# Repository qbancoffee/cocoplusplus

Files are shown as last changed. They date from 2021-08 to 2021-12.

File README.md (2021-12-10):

# CoCo++
I spent some time transcribing the CoCo 3 schematic into KiCAD to contribute to the bit preserve project.
Using that schematic, I created a drop in replacement board which I subsequently ordered, assembled, and tested.
At this point I consider that project done and time to move on. If you are interested in the bit preserve
project here is the link.<br>
[Bit Preserve, recreating classic computer schematics](https://github.com/baldengineer/bit-preserve)

So now it's time to have fun....<br>
I want to base this board on the CoCo 3 for several reasons.

- It's the latest real CoCo.
- I never used one in my youth.
- When people upgrade to to the GIME-X, they may want to use their otherwise unused GIME
- If used with a GIME-X then there would be a new CoCo added to the world. 

To start this I stripped the CoCo 3 portion out of the bit-preserve project and
created this repository so that I could make changes to the board that I would like to see. I'm making
this available so that anyone can contribute ideas and expertise.

### Goals
I still don't know what all of the goals are but I'll list some ideas that I've had or that others have mentioned or recommended.
- Having fun
- Mod for potential DMA
- USB keyboard
- Reduce overall size 
- A different form factor
- [Fit it in a polycase ZN-45](https://www.polycase.com/zn-45)
- HDMI or VGA out
- Composite out
- Surface mount components
- 12V power supply with standard barrel connector
- Replace DAC/ADC chip with equivalent circuitry
- Replace SALT chip with equivalent circuitry

### Videos
- [Testing new CoCo 3 board](https://youtu.be/XzGmMZHgejc)
- [Running NitrOS 9 Ease Of Use](https://youtu.be/wSlYcxvCpys)

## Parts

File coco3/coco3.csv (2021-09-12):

Reference | Quantity | Value | Footprint | Datasheet | Manufacturer part# | Vendor | Vendor part# | Manufacturer 2nd part# | Vendor 2nd part# | C90157 | LCSC | MMBT9014C | AVAILABILITY | DESCRIPTION | MF | MP | PACKAGE | PRICE
BREAKOUT0 | 1 | Conn_01x18_Male | Connector_PinHeader_2.54mm:PinHeader_1x18_P2.54mm_Vertical | ~
C1004 C1003 C1002 | 3 | .47uF | Capacitor_SMD:C_0805_2012Metric_Pad1.18x1.45mm_HandSolder | https://datasheet.lcsc.com/lcsc/1810251812_Samsung-Electro-Mechanics-CL21B474KBFNNNE_C13967.pdf | CL21B474KBFNNNE | JLCPCB | C13967
C15 C63 | 2 | 220uF 25V | Capacitor_SMD:CP_Elec_8x10 | https://datasheet.lcsc.com/lcsc/1809291333_Lelon-VEJ221M1ETR-0810_C134765.pdf | VEJ221M1ETR-0810 | JLCPCB | C134765
C18 C19 C23 C22 | 4 | 1800pF | Capacitor_SMD:C_0805_2012Metric_Pad1.18x1.45mm_HandSolder | https://datasheet.lcsc.com/lcsc/1811061740_FH-Guangdong-Fenghua-Advanced-Tech-0805B182K500NT_C1722.pdf | 0805B182K500NT | JLCPCB | C1722
C2 C56 C55 | 3 | 10uF 25v | Capacitor_SMD:CP_Elec_4x5.3 | https://datasheet.lcsc.com/lcsc/1809291326_Lelon-VE-100M1ETR-0405_C134721.pdf | VE-100M1ETR-0405 | JLCPCB | C134721
C24 | 1 | 10uF NP | Capacitor_THT:C_Radial_D6.3mm_H5.0mm_P2.50mm | https://products.nichicon.co.jp/en/pdf/XJA043/e-uvp.pdf | UVP1E100MDD1TD | digikey | 493-12688-1-ND
C26 C4 C1 C28 C14 C6 C7 C13 C47 C48 C1001 C51 C50 C42 C39 C41 C38 C40 C12 C8 | 20 | .1uF | Capacitor_SMD:C_0805_2012Metric_Pad1.18x1.45mm_HandSolder | https://datasheet.lcsc.com/lcsc/1811121310_Samsung-Electro-Mechanics-CL21A106KAYNNNE_C15850.pdf | CL21A106KAYNNNE | JLCPCB | C15850
C27 | 1 | 100uF 16v | Capacitor_SMD:CP_Elec_6.3x5.3 | https://datasheet.lcsc.com/lcsc/1811051603_Lelon-VEJ101M1CTR-0605_C164064.pdf | VEJ101M1CTR-0605 | JLCPCB | C164064
C29 | 1 | 4700uF 25V | Capacitor_SMD:CP_Elec_18x22 | https://datasheet.lcsc.com/lcsc/1811051717_Lelon-VEJ472M1ETR-1821_C249676.pdf | VEJ472M1ETR-1821 | JLCPCB | C249676
C3 | 1 | 1uF 50V | Capacitor_SMD:CP_Elec_4x5.4 | https://datasheet.lcsc.com/lcsc/2105211834_Honor-Elec-RVT1H1R0M0405_C3348.pdf | RVT1H1R0M0405 | JLCPCB | C3348
C34 | 1 | 100pF | Capacitor_SMD:C_0805_2012Metric_Pad1.18x1.45mm_HandSolder | https://datasheet.lcsc.com/lcsc/1810241824_Samsung-Electro-Mechanics-CL21C101JBANNNC_C1790.pdf | CL21C101JBANNNC | JLCPCB | C1790
C36 C25 C49 C17 C16 C21 C20 C57 | 8 | .022uF | Capacitor_SMD:C_0805_2012Metric_Pad1.18x1.45mm_HandSolder | https://datasheet.lcsc.com/lcsc/1810191222_Samsung-Electro-Mechanics-CL21B223KBANNNC_C1729.pdf | CL21B223KBANNNC | JLCPCB | C1729
C5 C53 C52 | 3 | .033uF | Capacitor_SMD:C_0805_2012Metric_Pad1.18x1.45mm_HandSolder | https://datasheet.lcsc.com/lcsc/1811061723_FH-Guangdong-Fenghua-Advanced-Tech-0805B333K500NT_C1739.pdf | 0805B333K500NT | JLCPCB | C1739
C54 | 1 | 470uF 16V | Capacitor_SMD:CP_Elec_8x10 | https://datasheet.lcsc.com/lcsc/1809291327_Lelon-VEJ471M1CTR-0810_C176671.pdf | VEJ471M1CTR-0810 | JLCPCB | C176671
C60 | 1 | 33pF | Capacitor_SMD:C_0805_2012Metric_Pad1.18x1.45mm_HandSolder | https://datasheet.lcsc.com/lcsc/1810191222_Samsung-Electro-Mechanics-CL21C330JBANNNC_C1814.pdf | CL21C330JBANNNC | JLCPCB | C1814
C61 C37 C10 C11 | 4 | 39pF | Capacitor_SMD:C_0805_2012Metric_Pad1.18x1.45mm_HandSolder | https://datasheet.lcsc.com/lcsc/1810191333_Walsin-Tech-Corp-0805N390J500CT_C296098.pdf | 0805N390J500CT | JLCPCB | C296098
C64 | 1 | 150pF | Capacitor_SMD:C_0805_2012Metric_Pad1.18x1.45mm_HandSolder | https://datasheet.lcsc.com/lcsc/1811061722_FH-Guangdong-Fenghua-Advanced-Tech-0805B151K500NT_C1716.pdf | 0805B151K500NT | JLCPCB | C1716
C68 C59 C58 | 3 | 1000pF | Capacitor_SMD:C_0805_2012Metric_Pad1.18x1.45mm_HandSolder | https://datasheet.lcsc.com/lcsc/1808311543_Samsung-Electro-Mechanics-CL21B102KBCNNNC_C46653.pdf | CL21B102KBCNNNC | JLCPCB | C46653
C9 | 1 | 100uF 16V | Capacitor_SMD:CP_Elec_6.3x5.3 | https://datasheet.lcsc.com/lcsc/1811051603_Lelon-VEJ101M1CTR-0605_C164064.pdf | VEJ101M1CTR-0605 | JLCPCB | C164064
CN1 | 1 | Conn_02x20_Odd_Even | coco2:EBC20DRAS | https://s3.amazonaws.com/catalogspreads-pdf/PAGE50-51%20.100%20LP%20DS%20EYE%20RA.pdf | EBC20DRAS | digikey | S9672-ND
CN2 | 1 | Conn_01x16_Female | Connector_PinHeader_2.54mm:PinHeader_1x16_P2.54mm_Vertical | https://www.te.com/commerce/DocumentDelivery/DDEController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 | 6-520415-6 | digikey | A144434-ND
CN3 | 1 | Conn_02x05_Odd_Even | Connector_PinHeader_2.54mm:PinHeader_2x05_P2.54mm_Vertical | https://drawings-pdf.s3.amazonaws.com/11636.pdf | PRPC005DAAN-RC | digikey | S2011EC-05-ND
CN4000 | 1 | Conn_01x12_Female | Connector_PinSocket_2.54mm:PinSocket_1x12_P2.54mm_Vertical | https://app.adam-tech.com/products/download/data_sheet/203013/rs1-xx-g-data-sheet.pdf | PPTC121LFBN-RC | digikey | S6100-ND
CN56 | 1 | Conn_01x24_Female | Connector_PinSocket_2.54mm:PinSocket_1x24_P2.54mm_Vertical | https://media.digikey.com/pdf/Data%20Sheets/Sullins%20PDFs/Female_Headers.100_DS.pdf | PPTC241LFBN-RC | digikey | S7022-ND
CN7 | 1 | Jack-DC | Connector_BarrelJack:BarrelJack_CUI_PJ-063AH_Horizontal | https://www.cuidevices.com/product/resource/digikeypdf/pj-063ah.pdf | PJ-063AH | digikey | CP-063AH-ND
D1001 | 1 | 5A 40V | Diode_SMD:D_SMB | https://datasheet.lcsc.com/lcsc/2011241905_MDD-Microdiode-Electronics-SS54B_C32513.pdf | SS54B | LCSC | C32513
D11 D8 D9 D10 | 4 | 1KF20-04 | Diode_THT:D_A-405_P10.16mm_Horizontal | https://www.nteinc.com/specs/100to199/pdf/nte109.pdf | D-GE-GEN PURP 75V | digikey | 2368-NTE109-ND
D12 D5 D1002 D1003 D1004 | 5 | 1N4148 | Diode_SMD:D_SOD-323F | https://datasheet.lcsc.com/lcsc/1810101110_Changjiang-Electronics-Tech--CJ-1N4148WS_C2128.pdf | 1N4148WS | JLCPCB | C2128
FB8 FB6 FB9 FB10 FB5 | 5 |  | coco2:FB_28L0138-10R-10 | https://media.digikey.com/pdf/Data%20Sheets/Laird%20Technologies/Ferrite_EMI_Cable_Cores.pdf | 28L0138-10R-10 | digikey | 240-2438-1-ND
H1 H2 | 2 | MountingHole | MountingHole:MountingHole_3.5mm | ~
H3 | 1 | MountingHole | coco2:coco3_outline_and_layout | ~
IC1 | 1 | MC6809E | Package_DIP:DIP-40_W15.24mm_Socket | https://datasheet.lcsc.com/lcsc/1810201609_Ckmtw-Shenzhen-Cankemeng-Z-ICS0S40P-W000_C132506.pdf | Z-ICS0S40P-W000 | JLCPCB | C132506
IC12 IC10 IC11 | 3 | 74LS244 | Package_SO:SOIC-20W_7.5x12.8mm_P1.27mm | https://datasheet.lcsc.com/lcsc/1809192013_Texas-Instruments-SN74LS244DWR_C7751.pdf | SN74LS244DWR | JLCPCB | C7751
IC13 | 1 | 74LS374 | Package_SO:SOIC-20W_7.5x12.8mm_P1.27mm | https://datasheet.lcsc.com/lcsc/1809251730_Texas-Instruments-SN74LS374NSR_C7764.pdf | SN74LS374NSR | JLCPCB | C7764
IC14 | 1 | 74LS30 | Package_SO:SOIC-14_3.9x8.7mm_P1.27mm | https://datasheet.lcsc.com/lcsc/1809051422_Texas-Instruments-SN74LS30DR_C7759.pdf | SN74LS30DR | JLCPCB | C7759
IC15 | 1 | 74LS04 | Package_SO:SOIC-14_3.9x8.7mm_P1.27mm | https://datasheet.lcsc.com/lcsc/1810292010_Texas-Instruments-SN74LS04DR_C6796.pdf | SN74LS04DR | JLCPCB | C6796
IC2 | 1 | 27C256 | Package_DIP:DIP-28_W15.24mm_Socket | https://ww1.microchip.com/downloads/en/DeviceDoc/doc0014.pdf | AT27C256R-45PU | digikey | AT27C256R-45PU-ND
IC3 | 1 | SN74LS245N | Package_SO:SOIC-20W_7.5x12.8mm_P1.27mm | https://datasheet.lcsc.com/lcsc/1810010228_Texas-Instruments-SN74LS245DWR_C129580.pdf | SN74LS245DWR | JLCPCB | C129580
IC36 | 1 | MC78L08_TO92 | Package_TO_SOT_THT:TO-92_Inline | https://www.ti.com/general/docs/suppproductinfo.tsp?distId=10 | UA78L08ACLPRE3 | digikey | 296-UA78L08ACLPRE3CT-ND
IC5 IC4 | 2 | W65C21N6TPLG-14 | Package_LCC:PLCC-44_THT-Socket | https://www.mouser.com/datasheet/2/436/w65c21-661.pdf
IC6 | 1 | TCC1014 | Package_LCC:PLCC-68_THT-Socket | http://www.assmann-wsw.com/uploads/datasheets/ASS_7007_CO.pdf | A-CCS 068-G-T | digikey | AE11249-ND
IC7 | 1 | SC77526 | Package_DIP:DIP-20_W7.62mm_Socket | http://www.cnctech.us/pdfs/243-XX-1-XX_.pdf | 243-20-1-03 | digikey | 1175-1479-ND
IC9 | 1 | 74LS138 | Package_SO:SOP-16_3.9x9.9mm_P1.27mm | https://datasheet.lcsc.com/lcsc/2004251708_XINLUDA-XL74LS138_C513515.pdf | XL74LS138 | JLCPCB | C513515
J1001 | 1 | RGB_2_ADAPTER_ADAPTER | Connector_PinHeader_2.54mm:PinHeader_2x03_P2.54mm_Horizontal | https://cdn.amphenol-icc.com/media/wysiwyg/files/drawing/75867.pdf | 75867-131LF | digikey | 609-2846-ND
J1002 | 1 | Conn_01x04_Male | Connector_PinHeader_2.54mm:PinHeader_1x04_P2.54mm_Vertical | ~
J5 | 1 | SJ-435107RS | coco2:CUI_SJ-435107RS | https://www.cuidevices.com/product/resource/sj-435107.pdf |  |  |  |  |  |  |  |  | Good | 3.5 mm Right Angle Shielded _0.141, 1/8, Mini Plug_ Female HeadPhone Jack | CUI | SJ-435107RS | None | 1.04 USD
JK1 | 1 | Left Joystick | coco2:CUI_SDS-60J | https://www.cuidevices.com/product/resource/digikeypdf/sds-j.pdf | SDS-60J | digikey | CP-2360-ND
JK2 | 1 | Right Joystick | coco2:CUI_SDS-60J | https://www.cuidevices.com/product/resource/digikeypdf/sds-j.pdf | SDS-60J | digikey | CP-2360-ND
JK3 | 1 | RS232 | coco2:CUI_SDS-40J | https://www.cuidevices.com/product/resource/digikeypdf/sds-j.pdf | SDS-40J | digikey | CP-2340-ND
JK4 | 1 | Cassette | coco2:CUI_SDS-50J | https://www.cuidevices.com/product/resource/digikeypdf/sds-j.pdf | SDS-50J | digikey | CP-2350-ND
L1 | 1 | 1.8uH | Inductor_THT:L_Axial_L9.5mm_D4.0mm_P12.70mm_Horizontal_Fastron_SMCC | http://www.delevan.com/seriesPDFs/1537.pdf | 1537-18K | digikey | 1134-1090-1-ND
L1001 | 1 | 33uH | Inductor_SMD:L_Sumida_CDMC6D28_7.25x6.5mm | https://datasheet.lcsc.com/lcsc/1912111437_Sunlord-MWSA0605S-330MT_C408470.pdf | MWSA0605S-330MT | LSCSC | C408470
MP1 | 1 | 4.7k | Resistor_THT:R_Array_SIP10 | https://www.ctscorp.com/wp-content/uploads/2015/11/770.pdf | 770101472P | digikey | 770-101-R4.7KP-ND
MP2 | 1 | 4.7k | Resistor_THT:R_Array_SIP9 | https://www.bourns.com/docs/Product-Datasheets/4600H.pdf | 4609H-101-472LF | digikey | 4609H-101-472LF-ND
Q1001 | 1 | MMBT9014C | Package_TO_SOT_SMD:SOT-23 | https://www.onsemi.com/pub/Collateral/BC818-D.pdf |  |  |  |  |  | C90157 | LCSC | MMBT9014C
Q3 Q2 Q5 Q6 Q7 | 5 | 2SC945(NTE85) | Package_TO_SOT_THT:TO-92L_Inline | https://www.nteinc.com/specs/10to99/pdf/nte85.pdf | NTE85 | digikey | 2368-NTE85-ND
Q4 | 1 | MPSA13(NTE46) | Package_TO_SOT_THT:TO-92L_Inline | https://www.nteinc.com/specs/10to99/pdf/nte46.pdf | NTE46 | digikey | 2368-NTE46-ND
R1 R1003 R1002 | 3 | 100K | Resistor_SMD:R_1206_3216Metric_Pad1.30x1.75mm_HandSolder | https://datasheet.lcsc.com/lcsc/1810301421_UNI-ROYAL-Uniroyal-Elec-1206W4F1003T5E_C17900.pdf | 1206W4F1003T5E | JLCPCB | C17900
R1006 R1005 R1004 | 3 | 5.1K | Resistor_SMD:R_1206_3216Metric_Pad1.30x1.75mm_HandSolder | https://datasheet.lcsc.com/lcsc/1811060210_UNI-ROYAL-Uniroyal-Elec-1206W4F5101T5E_C26033.pdf | 1206W4F5101T5E | JLCPCB | C26033
R1007 | 1 | 20M | Resistor_SMD:R_1206_3216Metric_Pad1.30x1.75mm_HandSolder | https://datasheet.lcsc.com/lcsc/1810301437_UNI-ROYAL-Uniroyal-Elec-1206W4J0206T5E_C26125.pdf | 1206W4J0206T5E | JLCPCB | C26125
R12 R1001 R1008 | 3 | 10k | Resistor_SMD:R_1206_3216Metric_Pad1.30x1.75mm_HandSolder | https://datasheet.lcsc.com/lcsc/1810301434_UNI-ROYAL-Uniroyal-Elec-1206W4F1002T5E_C17902.pdf | 1206W4F1002T5E | JLCPCB | C17902
R13 | 1 | 100 1W | Resistor_SMD:R_2512_6332Metric_Pad1.40x3.35mm_HandSolder | https://datasheet.lcsc.com/lcsc/1810301126_UNI-ROYAL-Uniroyal-Elec-25121WF1000T4E_C35218.pdf | 25121WF1000T4E | JLCPCB | C35218
R14 | 1 | 220 1W | Resistor_SMD:R_2512_6332Metric_Pad1.40x3.35mm_HandSolder | https://datasheet.lcsc.com/lcsc/1810301127_UNI-ROYAL-Uniroyal-Elec-25121WJ0221T4E_C38808.pdf | 25121WJ0221T4E | JLCPCB | C38808
R23 | 1 | 82 | Resistor_SMD:R_1206_3216Metric_Pad1.30x1.75mm_HandSolder | https://datasheet.lcsc.com/lcsc/1810301412_UNI-ROYAL-Uniroyal-Elec-1206W4F820JT5E_C17980.pdf | 1206W4F820JT5E | JLCPCB | C17980
R27 | 1 | 1.5K | Resistor_SMD:R_1206_3216Metric_Pad1.30x1.75mm_HandSolder | https://datasheet.lcsc.com/lcsc/1810301424_UNI-ROYAL-Uniroyal-Elec-1206W4F1501T5E_C26030.pdf | UNI-ROYAL(Uniroyal Elec) | JLCPCB | C26030
R29 | 1 | 3.9K | Resistor_SMD:R_1206_3216Metric_Pad1.30x1.75mm_HandSolder | https://datasheet.lcsc.com/lcsc/1810301411_UNI-ROYAL-Uniroyal-Elec-1206W4F3901T5E_C17883.pdf | 1206W4F3901T5E | JLCPCB | C17883
R31 | 1 | 39K | Resistor_SMD:R_1206_3216Metric_Pad1.30x1.75mm_HandSolder | https://datasheet.lcsc.com/lcsc/1810301435_UNI-ROYAL-Uniroyal-Elec-1206W4F3902T5E_C18008.pdf | 1206W4F3902T5E | JLCPCB | C18008
R32 | 1 | 20K | Resistor_SMD:R_1206_3216Metric_Pad1.30x1.75mm_HandSolder | https://datasheet.lcsc.com/lcsc/1810301422_UNI-ROYAL-Uniroyal-Elec-1206W4F620KT5E_C25344.pdf | 1206W4F620KT5E | JLCPCB | C25344
R34 R30 R69 | 3 | 100 | Resistor_SMD:R_1206_3216Metric_Pad1.30x1.75mm_HandSolder | https://datasheet.lcsc.com/lcsc/1810301422_UNI-ROYAL-Uniroyal-Elec-1206W4F1000T5E_C17901.pdf | 1206W4F1000T5E | JLCPCB | C17901
R35 R33 | 2 | 220K | Resistor_SMD:R_1206_3216Metric_Pad1.30x1.75mm_HandSolder | https://datasheet.lcsc.com/lcsc/1810301411_UNI-ROYAL-Uniroyal-Elec-1206W4F2203T5E_C17956.pdf | 1206W4F2203T5E | JLCPCB | C17956
R36 R40 R47 R54 | 4 | 1K | Resistor_SMD:R_1206_3216Metric_Pad1.30x1.75mm_HandSolder | https://datasheet.lcsc.com/lcsc/1810242121_UNI-ROYAL-Uniroyal-Elec-1206W4F1001T5_C4410.pdf | 1206W4F1001T5 | JLCPCB | C4410
R38 R45 R52 | 3 | 3K | Resistor_SMD:R_1206_3216Metric_Pad1.30x1.75mm_HandSolder | https://datasheet.lcsc.com/lcsc/1810301427_UNI-ROYAL-Uniroyal-Elec-1206W4F3001T5E_C18012.pdf | 1206W4F3001T5E | JLCPCB | C18012
R4 R2 R3 R5 R21 R7 R59 R6 R24 R62 R61 R8 R11 | 13 | 4.7K | Resistor_SMD:R_1206_3216Metric_Pad1.30x1.75mm_HandSolder | https://datasheet.lcsc.com/lcsc/1810301414_UNI-ROYAL-Uniroyal-Elec-1206W4F4701T5E_C17936.pdf | 1206W4F4701T5E | JLCPCB | C17936
R42 R49 R56 | 3 | 2K | Resistor_SMD:R_1206_3216Metric_Pad1.30x1.75mm_HandSolder | https://datasheet.lcsc.com/lcsc/1811091710_UNI-ROYAL-Uniroyal-Elec-1206W4F2001T5E_C17944.pdf | 1206W4F2001T5E | JLCPCB | C17944
R63 | 1 | 150 | Resistor_SMD:R_1206_3216Metric_Pad1.30x1.75mm_HandSolder | https://datasheet.lcsc.com/lcsc/1809140241_UNI-ROYAL-Uniroyal-Elec-1206W4F1500T5E_C17917.pdf | 1206W4F1500T5E | JLCPCB | C17917
R64 R9 R10 | 3 | 47 | Resistor_SMD:R_1206_3216Metric_Pad1.30x1.75mm_HandSolder | https://datasheet.lcsc.com/lcsc/1811101020_UNI-ROYAL-Uniroyal-Elec-1206W4J0470T5E_C25384.pdf | 1206W4J0470T5E | JLCPCB | C25384
R65 | 1 | 1M | Resistor_SMD:R_1206_3216Metric_Pad1.30x1.75mm_HandSolder | https://datasheet.lcsc.com/lcsc/1811050105_UNI-ROYAL-Uniroyal-Elec-1206W4F1004T5E_C17927.pdf | 1206W4F1004T5E | JLCPCB | C17927
R66 | 1 | 7.5K | Resistor_SMD:R_1206_3216Metric_Pad1.30x1.75mm_HandSolder | https://datasheet.lcsc.com/lcsc/1810171732_UNI-ROYAL-Uniroyal-Elec-1206W4F7501T5E_C17978.pdf | 1206W4F7501T5E | JLCPCB | C17978
R70 | 1 | 470 | Resistor_SMD:R_1206_3216Metric_Pad1.30x1.75mm_HandSolder | https://datasheet.lcsc.com/lcsc/1809192114_UNI-ROYAL-Uniroyal-Elec-1206W4J0471T5E_C25383.pdf | 1206W4J0471T5E | JLCPCB | C25383
R71 R68 R28 R39 R46 R53 | 6 | 10 | Resistor_SMD:R_1206_3216Metric_Pad1.30x1.75mm_HandSolder | https://datasheet.lcsc.com/lcsc/1810301421_UNI-ROYAL-Uniroyal-Elec-1206W4F100JT5E_C17903.pdf | 1206W4F100JT5E | JLCPCB | C17903
R72 R43 R50 R57 R22 | 5 | 120 | Resistor_SMD:R_1206_3216Metric_Pad1.30x1.75mm_HandSolder | https://datasheet.lcsc.com/lcsc/1809140216_UNI-ROYAL-Uniroyal-Elec-1206W4F1200T5E_C17909.pdf | 1206W4F1200T5E | JLCPCB | C17909
RY1 | 1 | J0971CS5VDC.45 | coco2:RELAY_J0971CS5VDC.45 | https://www.citrelay.com/Catalog%20Pages/RelayCatalog/J097.pdf | J0971CS5VDC.45 | digikey | 2449-J0971CS5VDC.45-ND
SW1 | 1 | SW_DPDT_x2 | coco2:F2UEE | https://www.ckswitches.com/media/1402/fpush.pdf | F2UEE | digikey | 401-1223-ND
SW2 | 1 | Reset Switch | coco2:B3F3152 | https://omronfs.omron.com/en_US/ecb/products/pdf/en-b3f.pdf | B3F-3152 | digikey | SW410-ND | B32-1010 | SW451-ND
TC1 | 1 | 10pF-50pF | coco2:C_Rect_L7.2mm_W7.2mm_P5.00mm_FKS2_FKP2_MKS2_MKP2 | https://media.digikey.com/pdf/Data%20Sheets/EW%20Electronics-Edmar/GKGxx015_016_Series_DS.pdf | GKG60015 | digikey | 2447-GKG60015-ND
TP1001 | 1 | 5V | TestPoint:TestPoint_Pad_3.0x3.0mm | ~
TP2 | 1 | ECLK | TestPoint:TestPoint_Pad_3.0x3.0mm | ~
TP3 | 1 | QCLK | TestPoint:TestPoint_Pad_3.0x3.0mm | ~
TP4 | 1 | ~RAS | TestPoint:TestPoint_Pad_3.0x3.0mm | ~
TP5 | 1 | ~CAS | TestPoint:TestPoint_Pad_3.0x3.0mm | ~
TP6 | 1 | CVIDEO | TestPoint:TestPoint_Pad_3.0x3.0mm | ~
TP7 | 1 | VIDEO | TestPoint:TestPoint_Pad_3.0x3.0mm | ~
TP8 | 1 | RED OUT | TestPoint:TestPoint_Pad_3.0x3.0mm | ~
U1001 | 1 | LM2596S-5 | Package_TO_SOT_SMD:TO-263-5_TabPin3 | http://www.ti.com/lit/ds/symlink/lm2596.pdf | LM2596SX-5.0/NOPB | LCSC | C10002
U1002 | 1 | MAX3232 | Package_SO:SOIC-16_3.9x9.9mm_P1.27mm | https://datasheet.lcsc.com/lcsc/1809081207_Maxim-Integrated-MAX3232ESE+T_C15846.pdf | MAX3232ESE+T | LCSC | C15846
U1003 | 1 | LM393 | Package_SO:TSSOP-8_4.4x3mm_P0.65mm | http://www.ti.com/lit/ds/symlink/lm393.pdf | LM393PT | LCSC | C160466
X1 | 1 | 28.63636 MHz | coco2:XTAL_ECS-286.3-20-46X | https://ecsxtal.com/store/pdf/HC-46X.pdf | ECS-286.3-20-46X | digikey | XC1766-ND

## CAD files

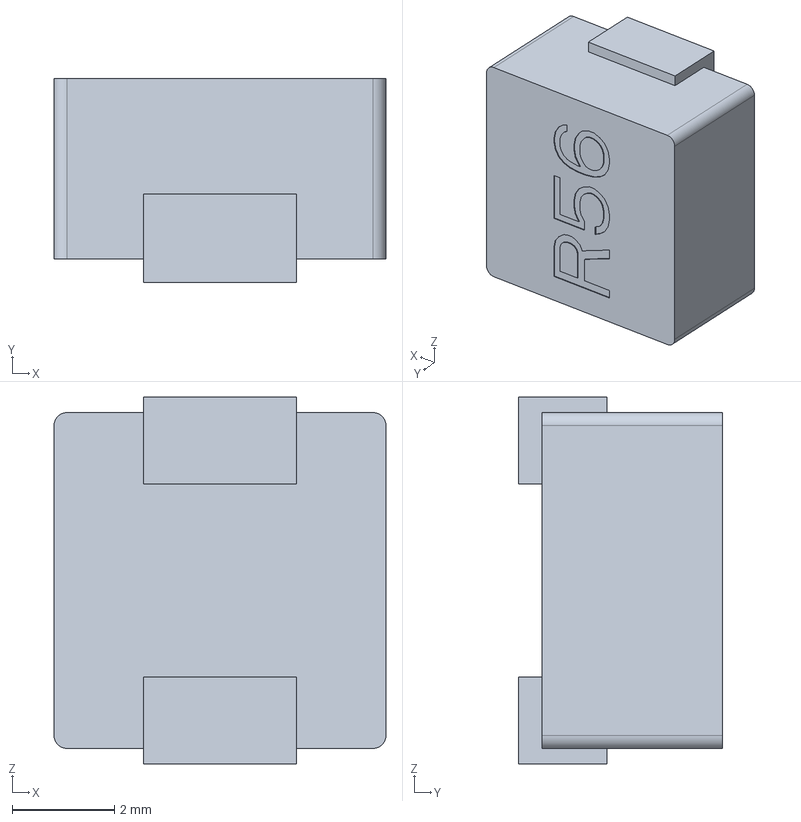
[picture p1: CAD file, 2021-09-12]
3d_models/SRP6540.stp
6.50 x 3.99 x 7.19 mm

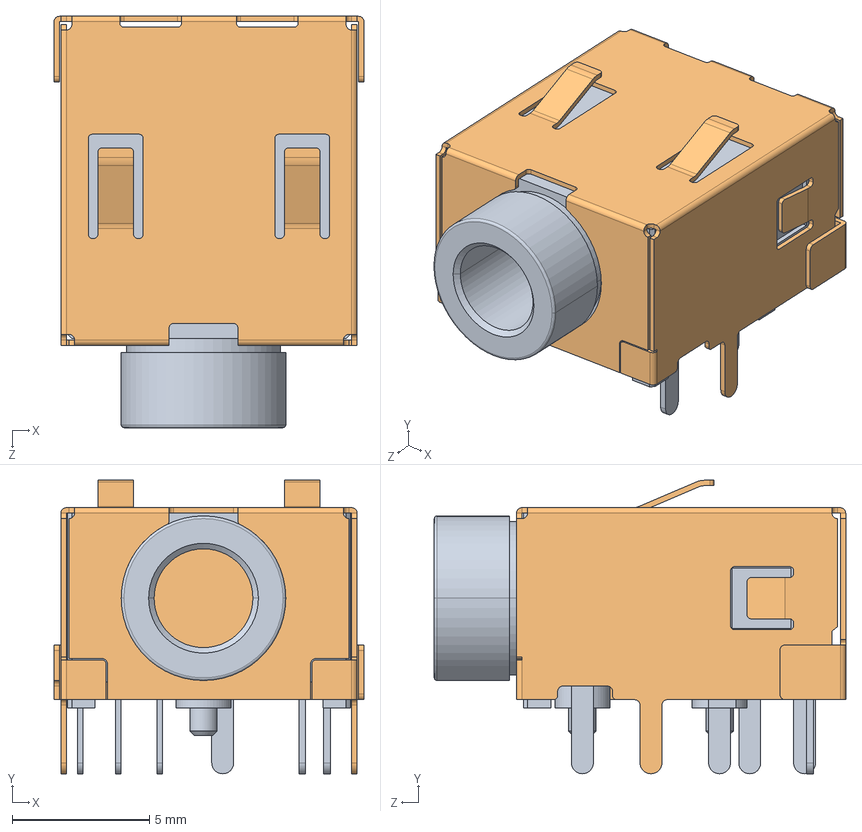
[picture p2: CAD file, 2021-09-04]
3d_models/CUI_DEVICES_SJ-435107RS.step
11.3 x 10.7 x 15.0 mm

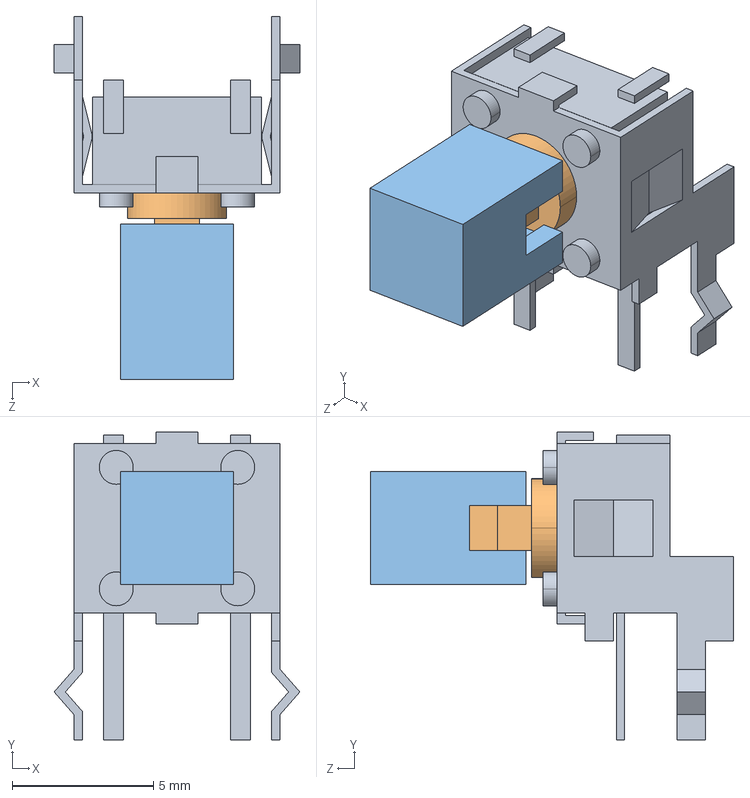
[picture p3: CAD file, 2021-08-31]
3d_models/reset_switch.step
8.70 x 10.9 x 12.9 mm
B3F_3155_BASE
B3F_3155_BUTTON
B32_1000

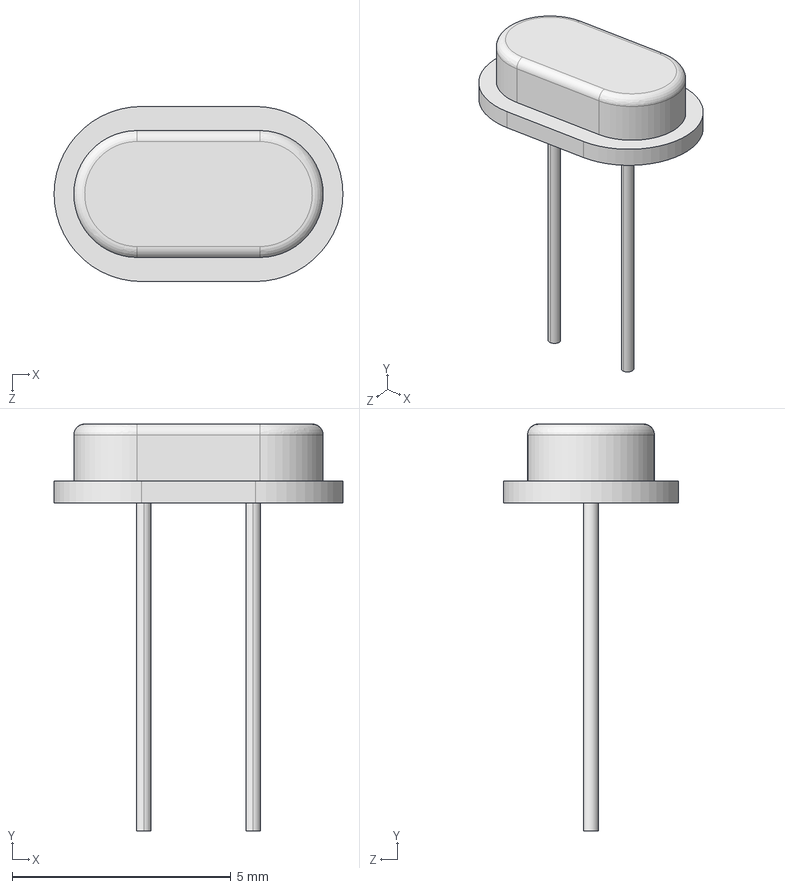
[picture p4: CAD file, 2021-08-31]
3d_models/ECS-286.3-20-46X.step
6.60 x 9.30 x 4.00 mm

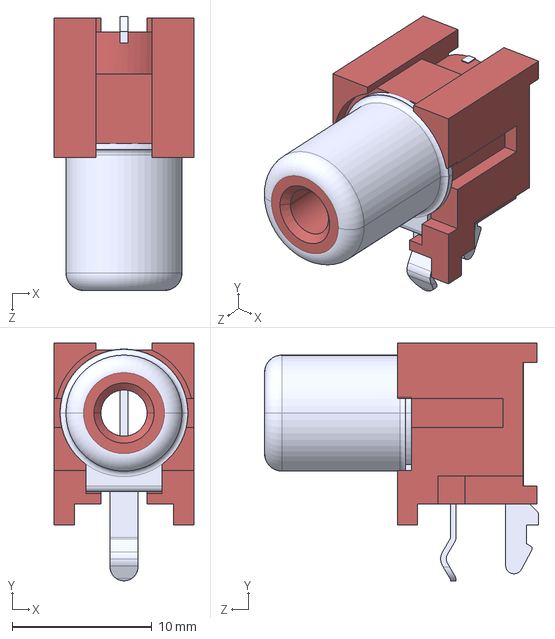
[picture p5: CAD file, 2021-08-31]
3d_models/KLPX-0848A-2-R_rA4.STEP
10.0 x 17.0 x 19.6 mm

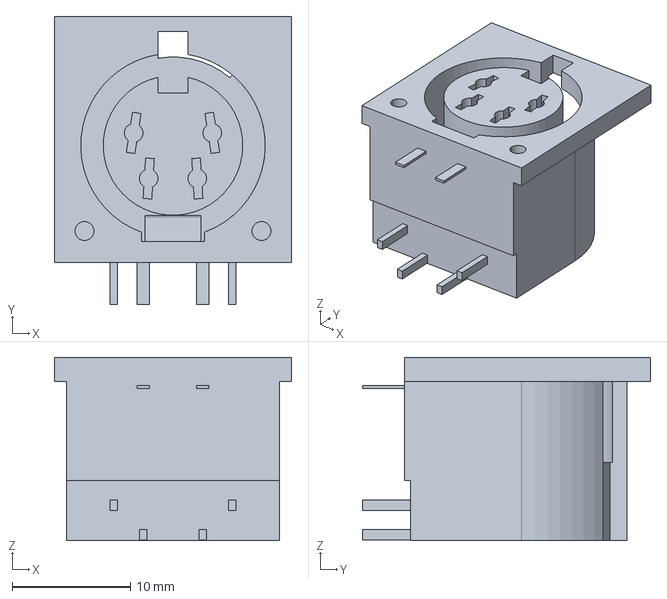
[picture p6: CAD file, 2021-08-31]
3d_models/DIN-4.stp
20.1 x 24.4 x 15.5 mm

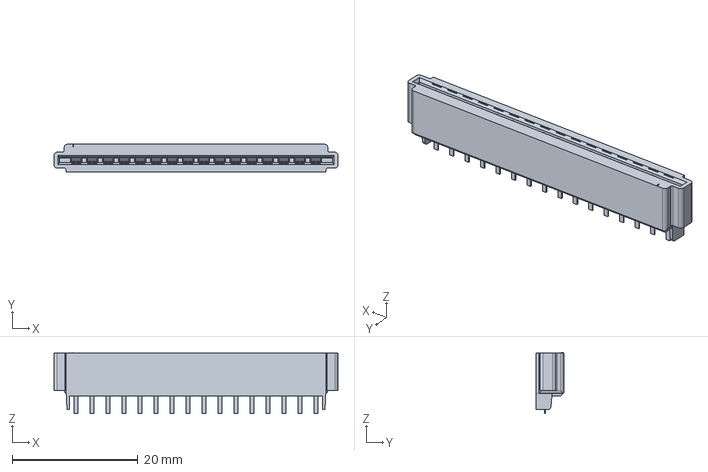
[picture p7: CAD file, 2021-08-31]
3d_models/keyboard_connector.stp
45.2 x 4.39 x 9.73 mm

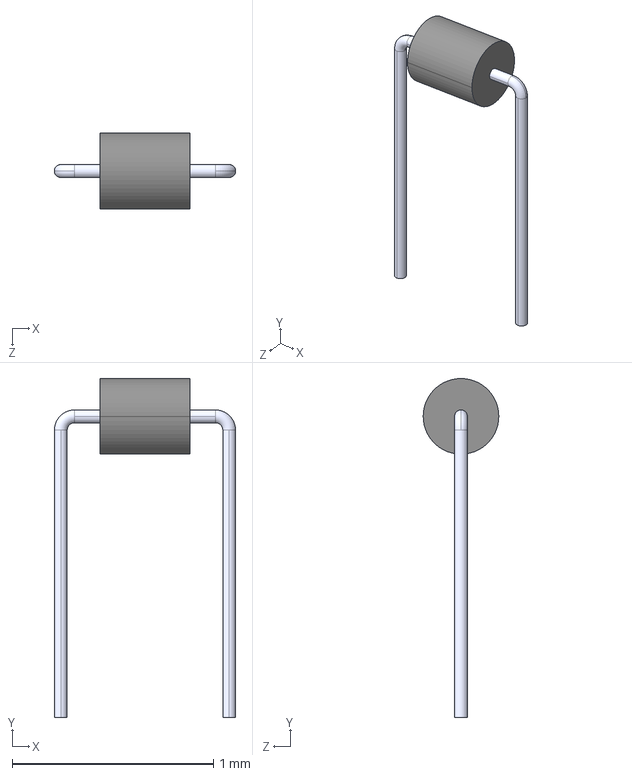
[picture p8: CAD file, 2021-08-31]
3d_models/28L0138-10R-10.step
0.901 x 1.68 x 0.376 mm

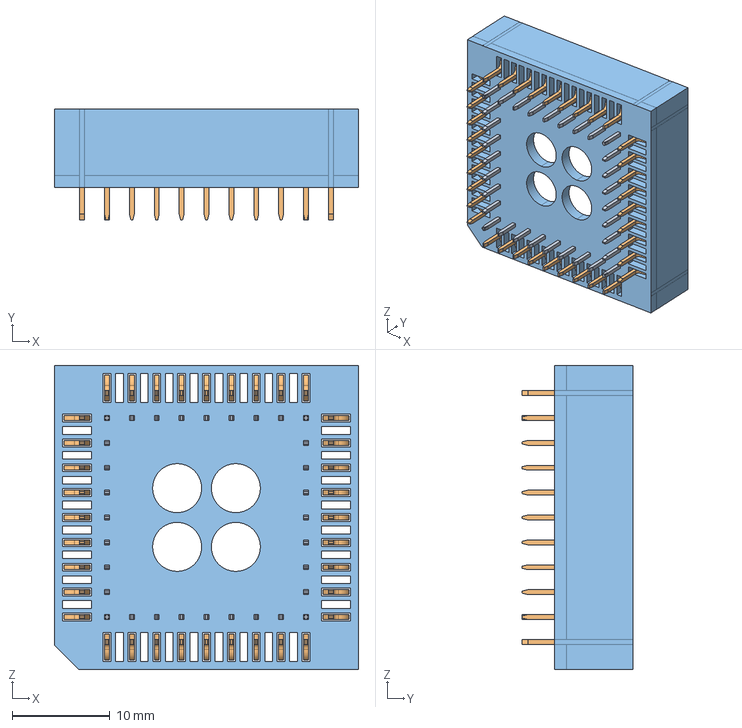
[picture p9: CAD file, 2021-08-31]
3d_models/a-ccs_068-z-t.stp
31.1 x 11.4 x 31.1 mm

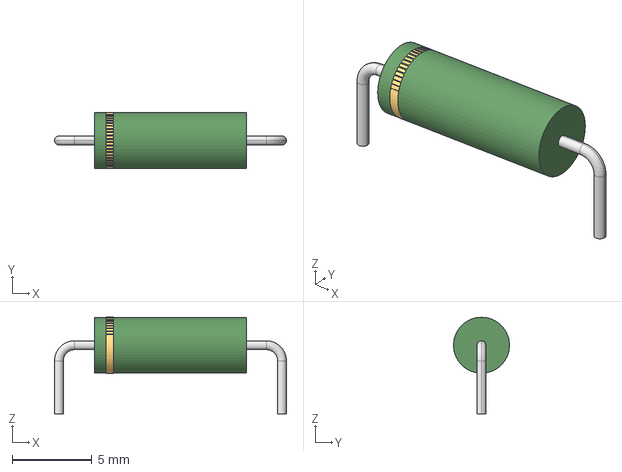
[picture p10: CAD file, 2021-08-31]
3d_models/ferrite_bead.step
14.5 x 3.51 x 6.05 mm

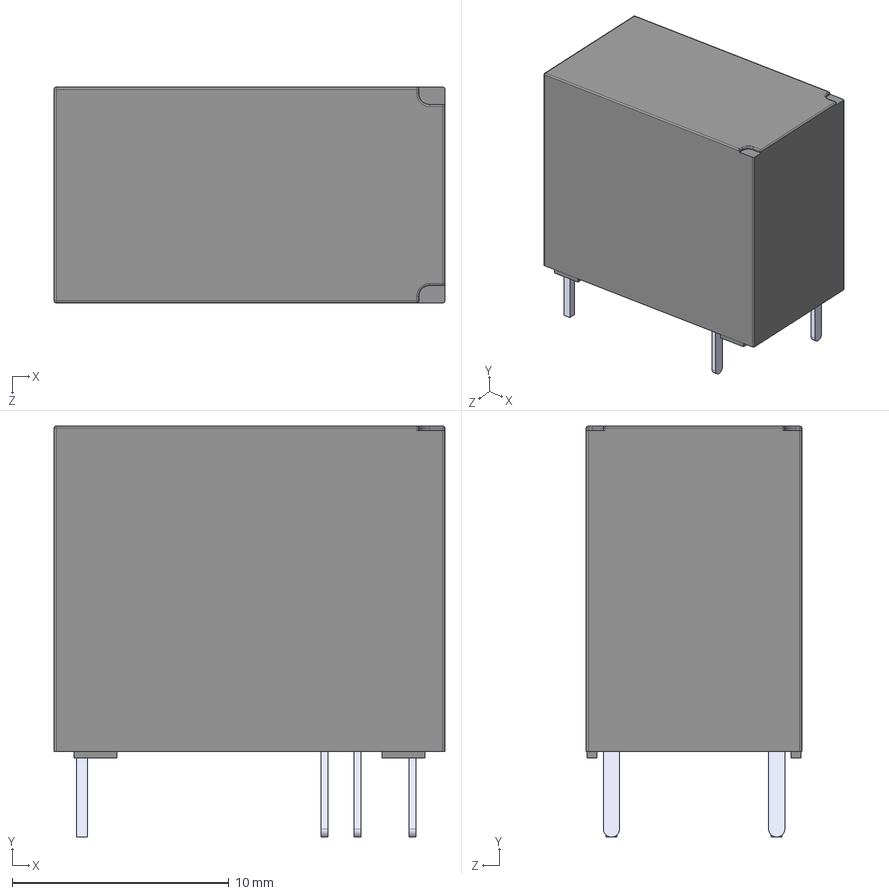
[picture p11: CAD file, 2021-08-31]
3d_models/J0971CS5VDC.45.step
18.0 x 19.0 x 9.95 mm

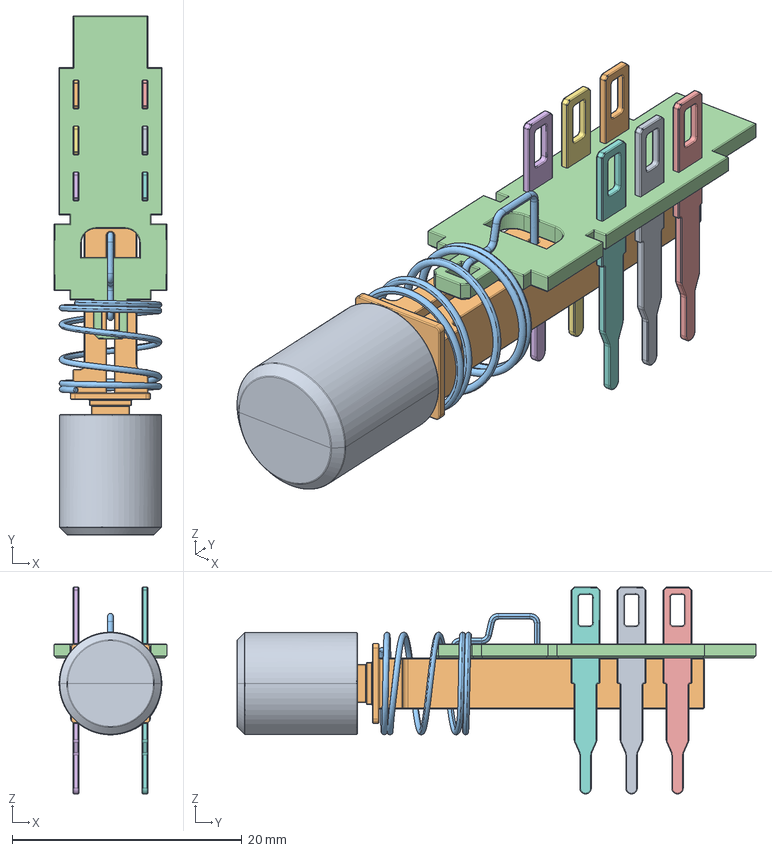
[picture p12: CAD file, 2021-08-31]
3d_models/switch.step
9.80 x 45.2 x 18.0 mm

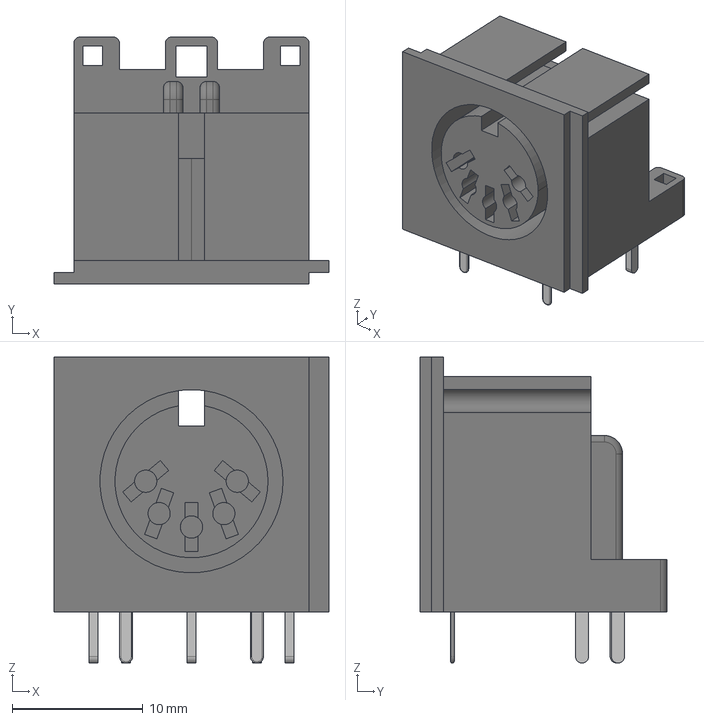
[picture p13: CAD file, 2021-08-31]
3d_models/din-5-jack.step
21.0 x 18.9 x 23.4 mm

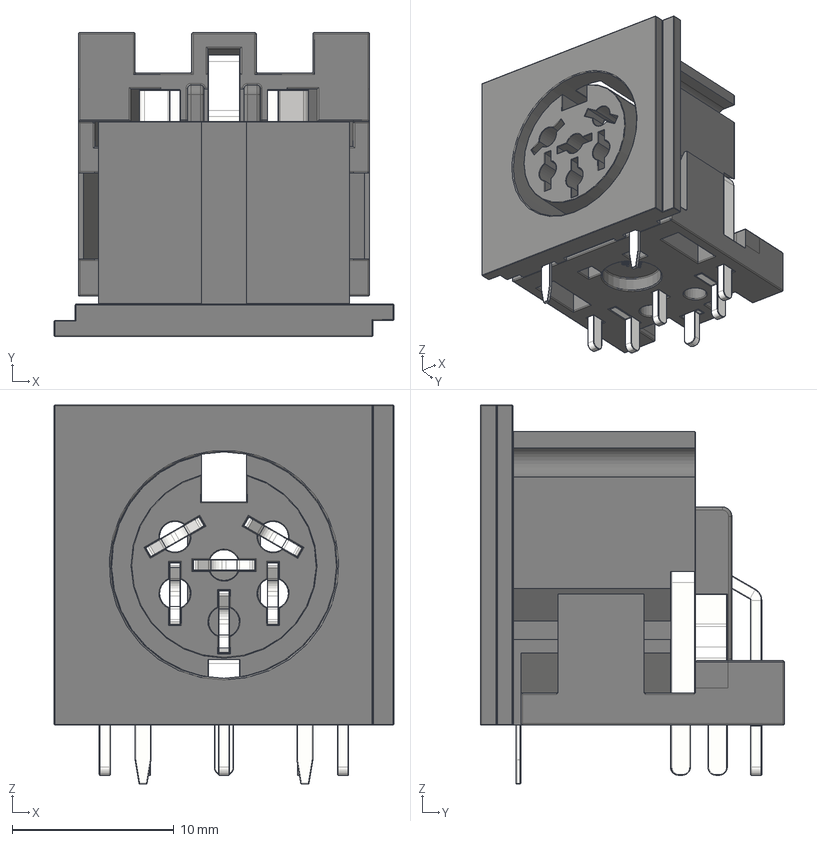
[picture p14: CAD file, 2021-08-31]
3d_models/DIN-6.step
21.0 x 18.8 x 23.4 mm
Baseplate IEC
Pin3
Pin4_2
Pin5_1
Pin6
Gnd pins
Housing

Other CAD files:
3d_models/KLPX-0848A-2-W_rA4.STEP
3d_models/B3F-3152.step
3d_models/EG1213.stp
3d_models/009652038.stp
3d_models/022182121.step

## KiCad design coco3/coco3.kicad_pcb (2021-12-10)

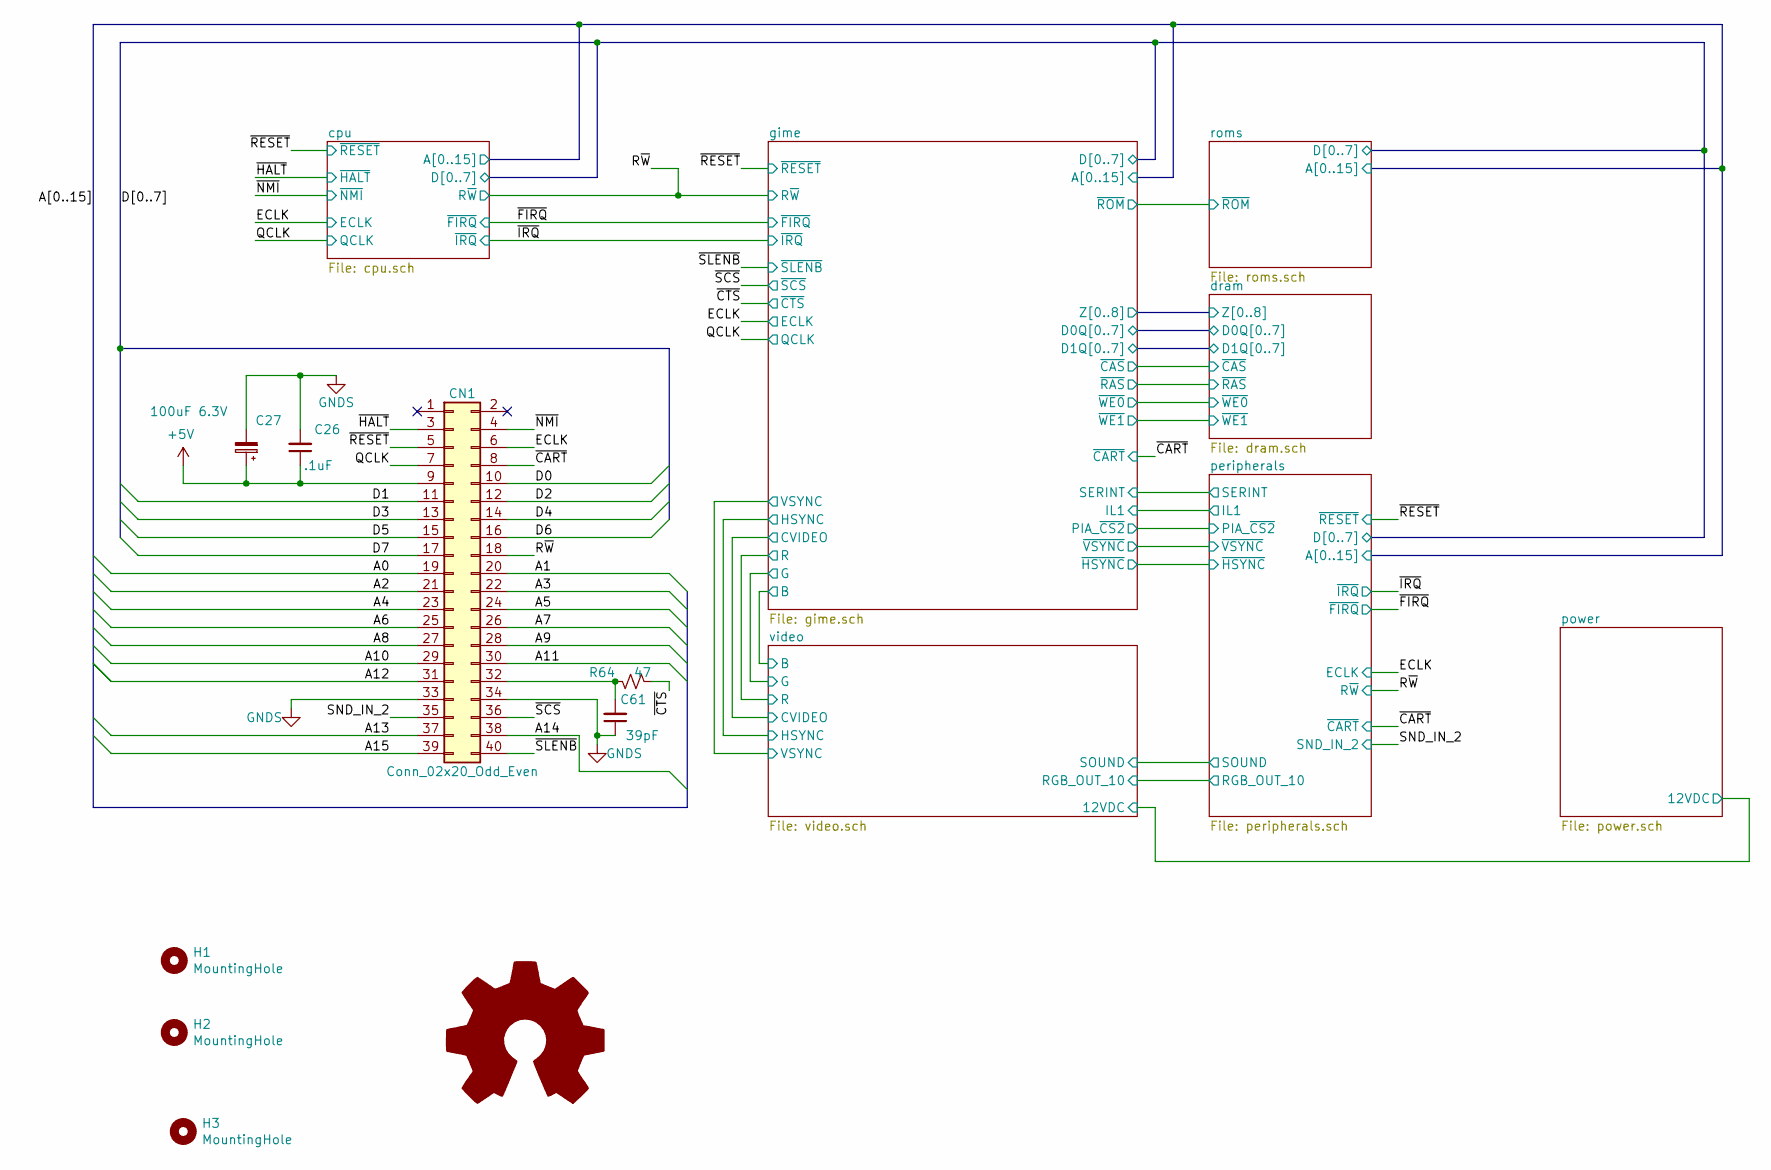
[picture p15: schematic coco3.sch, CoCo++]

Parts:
C26: .1uF; C_0805_2012Metric_Pad1.18x1.45mm_HandSolder; Manufacturer part# CL21A106KAYNNNE
C27: 100uF 6.3V; CP_EIA-3528-21_Kemet-B; Manufacturer part# TAJB107K006RNJ
C61: 39pF; C_0805_2012Metric_Pad1.18x1.45mm_HandSolder; Manufacturer part# 0805N390J500CT
CN1: Conn_02x20_Odd_Even; EBC20DRAS; Manufacturer part# EBC20DRAS
H1, H2: MountingHole; MountingHole_3.5mm
H3: MountingHole; coco3_outline_and_layout
R64: 47; R_1206_3216Metric_Pad1.30x1.75mm_HandSolder; Manufacturer part# 1206W4J0470T5E

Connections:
+5V: C26.1, C27.1, CN1.9; also elsewhere on the board
/A0: CN1.19; also elsewhere on the board
/A1: CN1.20; also elsewhere on the board
/A2: CN1.21; also elsewhere on the board
/A3: CN1.22; also elsewhere on the board
/A4: CN1.23; also elsewhere on the board
/A5: CN1.24; also elsewhere on the board
/A6: CN1.25; also elsewhere on the board
/A7: CN1.26; also elsewhere on the board
/A8: CN1.27; also elsewhere on the board
/A9: CN1.28; also elsewhere on the board
/A10: CN1.29; also elsewhere on the board
/A11: CN1.30; also elsewhere on the board
/A12: CN1.31; also elsewhere on the board
/A13: CN1.37; also elsewhere on the board
/A14: CN1.38; also elsewhere on the board
/A15: CN1.39; also elsewhere on the board
/D0: CN1.10; also elsewhere on the board
/D1: CN1.11; also elsewhere on the board
/D2: CN1.12; also elsewhere on the board
/D3: CN1.13; also elsewhere on the board
/D4: CN1.14; also elsewhere on the board
/D5: CN1.15; also elsewhere on the board
/D6: CN1.16; also elsewhere on the board
/D7: CN1.17; also elsewhere on the board
/ECLK: CN1.6; also elsewhere on the board
/QCLK: CN1.7; also elsewhere on the board
/R~W: CN1.18; also elsewhere on the board
/SND_IN_2: CN1.35; also elsewhere on the board
/~CART: CN1.8; also elsewhere on the board
/~CTS: R64.1; also elsewhere on the board
/~HALT: CN1.3; also elsewhere on the board
/~NMI: CN1.4; also elsewhere on the board
/~RESET: CN1.5; also elsewhere on the board
/~SCS: CN1.36; also elsewhere on the board
/~SLENB: CN1.40; also elsewhere on the board
GNDS: C26.2, C27.2, C61.1, CN1.33, CN1.34; also elsewhere on the board
unnamed: C61.2, CN1.32, R64.2

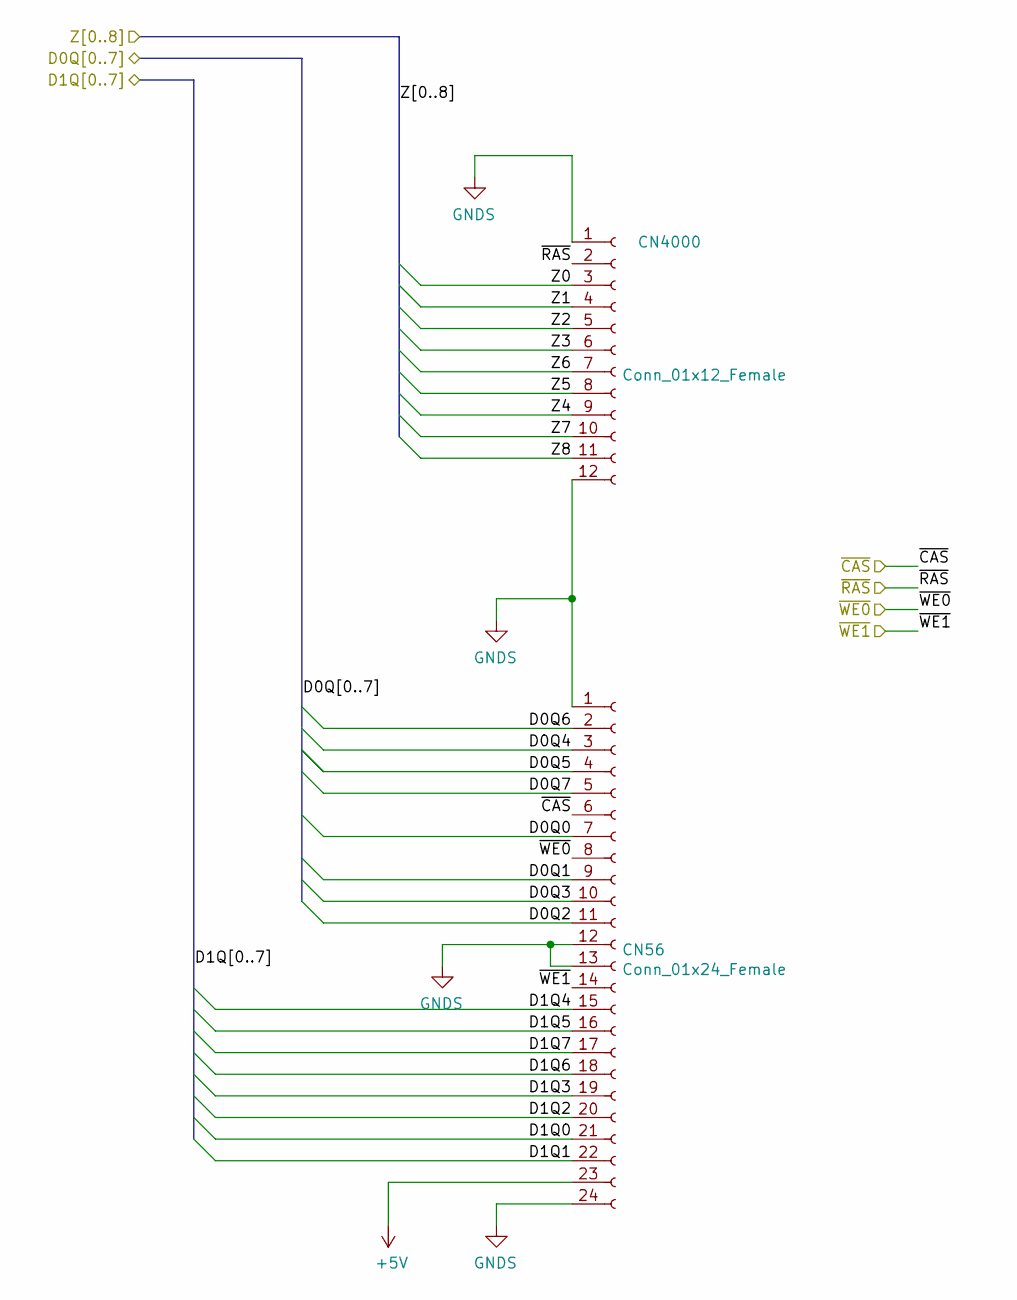
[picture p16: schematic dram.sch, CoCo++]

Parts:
CN56: Conn_01x24_Female; PinSocket_1x24_P2.54mm_Vertical; Manufacturer part# PPTC241LFBN-RC
CN4000: Conn_01x12_Female; PinSocket_1x12_P2.54mm_Vertical; Manufacturer part# PPTC121LFBN-RC

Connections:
+5V: CN56.23; also elsewhere on the board
/dram/D0Q0: CN56.7; also elsewhere on the board
/dram/D0Q1: CN56.9; also elsewhere on the board
/dram/D0Q2: CN56.11; also elsewhere on the board
/dram/D0Q3: CN56.10; also elsewhere on the board
/dram/D0Q4: CN56.3; also elsewhere on the board
/dram/D0Q5: CN56.4; also elsewhere on the board
/dram/D0Q6: CN56.2; also elsewhere on the board
/dram/D0Q7: CN56.5; also elsewhere on the board
/dram/D1Q0: CN56.21; also elsewhere on the board
/dram/D1Q1: CN56.22; also elsewhere on the board
/dram/D1Q2: CN56.20; also elsewhere on the board
/dram/D1Q3: CN56.19; also elsewhere on the board
/dram/D1Q4: CN56.15; also elsewhere on the board
/dram/D1Q5: CN56.16; also elsewhere on the board
/dram/D1Q6: CN56.18; also elsewhere on the board
/dram/D1Q7: CN56.17; also elsewhere on the board
/dram/Z0: CN4000.3; also elsewhere on the board
/dram/Z1: CN4000.4; also elsewhere on the board
/dram/Z2: CN4000.5; also elsewhere on the board
/dram/Z3: CN4000.6; also elsewhere on the board
/dram/Z4: CN4000.9; also elsewhere on the board
/dram/Z5: CN4000.8; also elsewhere on the board
/dram/Z6: CN4000.7; also elsewhere on the board
/dram/Z7: CN4000.10; also elsewhere on the board
/dram/Z8: CN4000.11; also elsewhere on the board
/dram/~CAS: CN56.6; also elsewhere on the board
/dram/~RAS: CN4000.2; also elsewhere on the board
/dram/~WE0: CN56.8; also elsewhere on the board
/dram/~WE1: CN56.14; also elsewhere on the board
GNDS: CN56.1, CN56.12, CN56.13, CN56.24, CN4000.1, CN4000.12; also elsewhere on the board

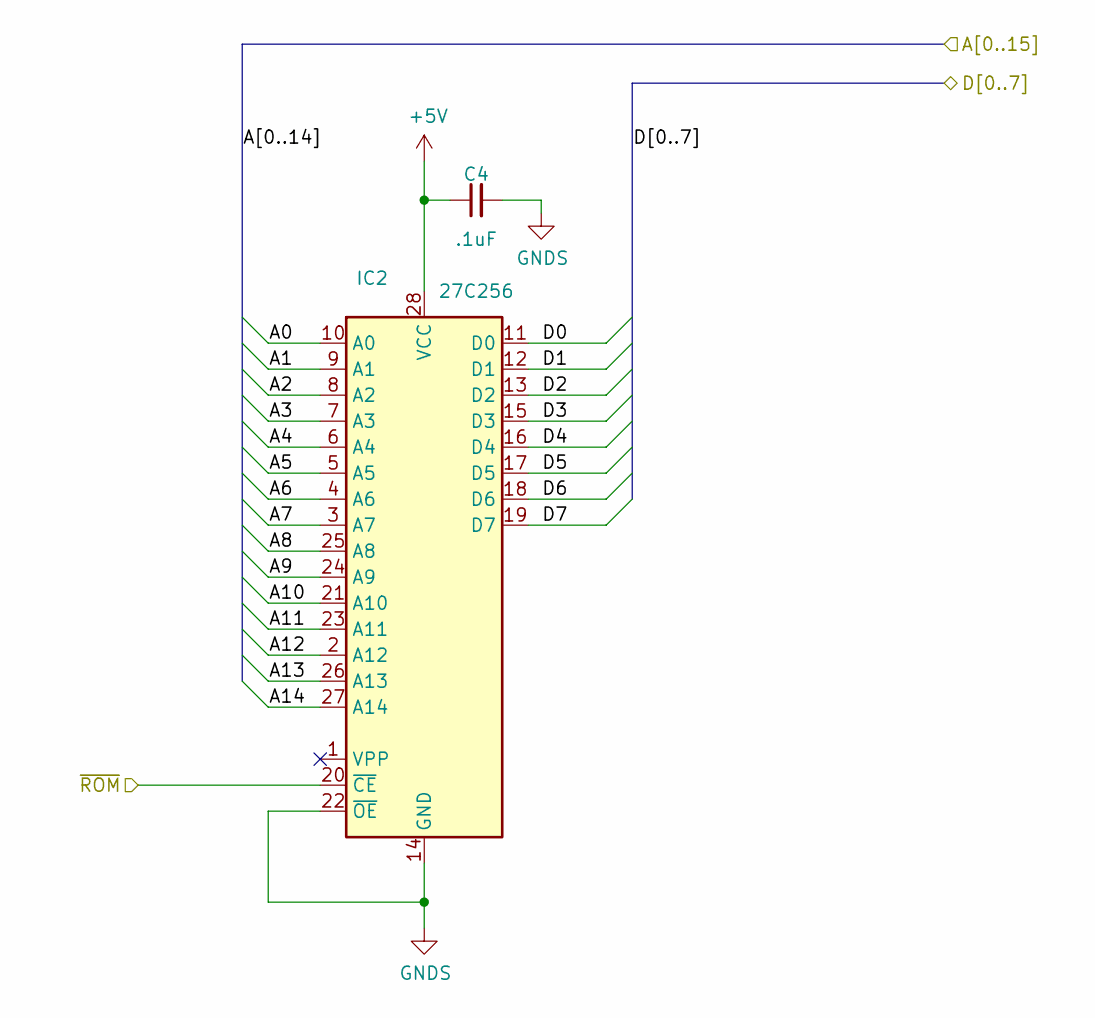
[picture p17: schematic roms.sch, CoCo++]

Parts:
C4: .1uF; C_0805_2012Metric_Pad1.18x1.45mm_HandSolder; Manufacturer part# CL21A106KAYNNNE
IC2: 27C256; DIP-28_W15.24mm_Socket; Manufacturer part# AT27C256R-45PU

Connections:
+5V: C4.1, IC2.28 (VCC); also elsewhere on the board
/A0: IC2.10 (A0); also elsewhere on the board
/A1: IC2.9 (A1); also elsewhere on the board
/A2: IC2.8 (A2); also elsewhere on the board
/A3: IC2.7 (A3); also elsewhere on the board
/A4: IC2.6 (A4); also elsewhere on the board
/A5: IC2.5 (A5); also elsewhere on the board
/A6: IC2.4 (A6); also elsewhere on the board
/A7: IC2.3 (A7); also elsewhere on the board
/A8: IC2.25 (A8); also elsewhere on the board
/A9: IC2.24 (A9); also elsewhere on the board
/A10: IC2.21 (A10); also elsewhere on the board
/A11: IC2.23 (A11); also elsewhere on the board
/A12: IC2.2 (A12); also elsewhere on the board
/A13: IC2.26 (A13); also elsewhere on the board
/A14: IC2.27 (A14); also elsewhere on the board
/D0: IC2.11 (D0); also elsewhere on the board
/D1: IC2.12 (D1); also elsewhere on the board
/D2: IC2.13 (D2); also elsewhere on the board
/D3: IC2.15 (D3); also elsewhere on the board
/D4: IC2.16 (D4); also elsewhere on the board
/D5: IC2.17 (D5); also elsewhere on the board
/D6: IC2.18 (D6); also elsewhere on the board
/D7: IC2.19 (D7); also elsewhere on the board
/gime/~ROM: IC2.20 (~CE); also elsewhere on the board
GNDS: C4.2, IC2.14 (GND), IC2.22 (~OE); also elsewhere on the board

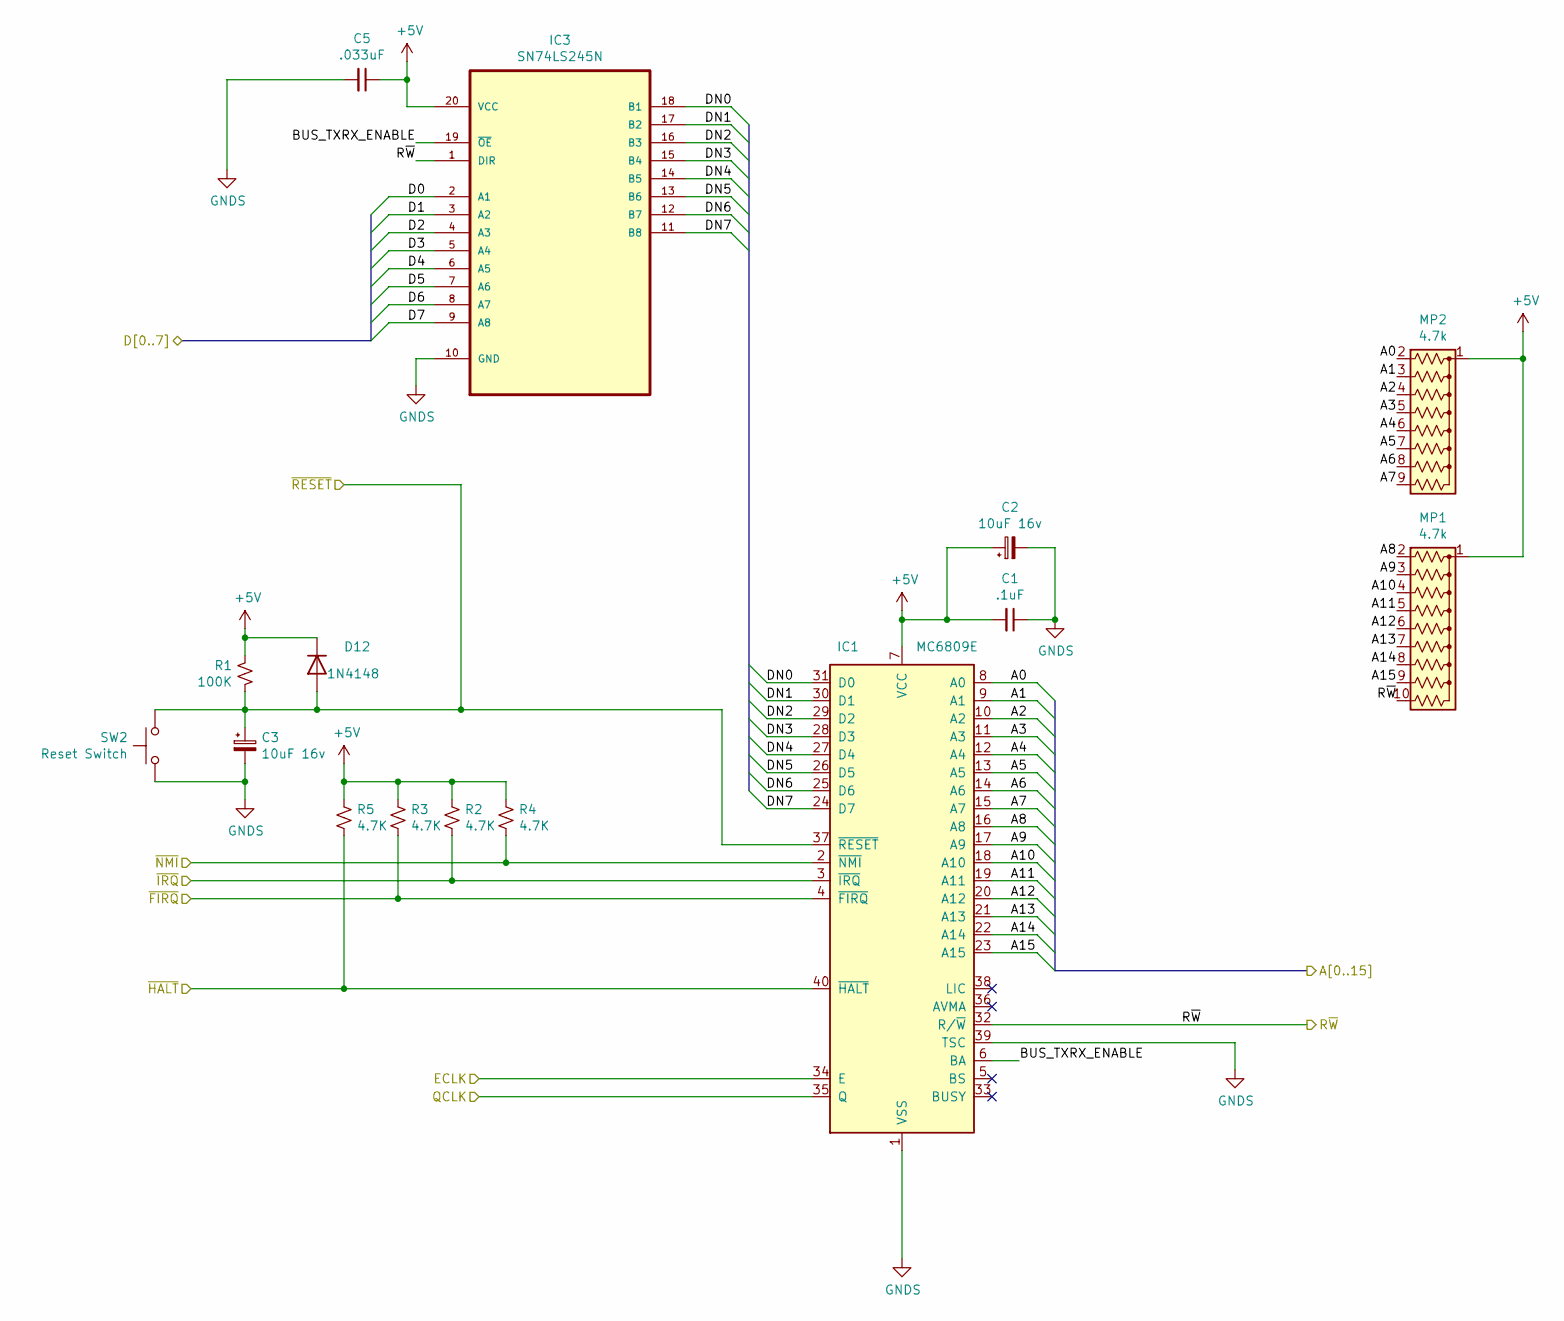
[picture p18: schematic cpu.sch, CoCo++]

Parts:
C1: .1uF; C_0805_2012Metric_Pad1.18x1.45mm_HandSolder; Manufacturer part# CL21A106KAYNNNE
C2, C3: 10uF 16v; CP_EIA-3216-18_Kemet-A; Manufacturer part# TAJA106K016RNJ
C5: .033uF; C_0805_2012Metric_Pad1.18x1.45mm_HandSolder; Manufacturer part# 0805B333K500NT
D12: 1N4148; D_SOD-323F; Manufacturer part# 1N4148WS
IC1: MC6809E; DIP-40_W15.24mm_Socket; Manufacturer part# Z-ICS0S40P-W000
IC3: SN74LS245N; SOIC-20W_7.5x12.8mm_P1.27mm; Manufacturer part# SN74LS245DWR
MP1: 4.7k; R_Array_SIP10; Manufacturer part# 770101472P
MP2: 4.7k; R_Array_SIP9; Manufacturer part# 4609H-101-472LF
R1: 100K; R_1206_3216Metric_Pad1.30x1.75mm_HandSolder; Manufacturer part# 1206W4F1003T5E
R2, R3, R4, R5: 4.7K; R_1206_3216Metric_Pad1.30x1.75mm_HandSolder; Manufacturer part# 1206W4F4701T5E
SW2: Reset Switch; B3F3152; Manufacturer part# B3F-3152

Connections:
+5V: C1.2, C2.1, C5.1, D12.1 (K), IC1.7 (VCC), IC3.20 (VCC), MP1.1 (common), MP2.1 (common), R1.1, R2.1, R3.1, R4.1, R5.1; also elsewhere on the board
/A0: IC1.8 (A0), MP2.2 (R1); also elsewhere on the board
/A1: IC1.9 (A1), MP2.3 (R2); also elsewhere on the board
/A2: IC1.10 (A2), MP2.4 (R3); also elsewhere on the board
/A3: IC1.11 (A3), MP2.5 (R4); also elsewhere on the board
/A4: IC1.12 (A4), MP2.6 (R5); also elsewhere on the board
/A5: IC1.13 (A5), MP2.7 (R6); also elsewhere on the board
/A6: IC1.14 (A6), MP2.8 (R7); also elsewhere on the board
/A7: IC1.15 (A7), MP2.9 (R8); also elsewhere on the board
/A8: IC1.16 (A8), MP1.2 (R1); also elsewhere on the board
/A9: IC1.17 (A9), MP1.3 (R2); also elsewhere on the board
/A10: IC1.18 (A10), MP1.4 (R3); also elsewhere on the board
/A11: IC1.19 (A11), MP1.5 (R4); also elsewhere on the board
/A12: IC1.20 (A12), MP1.6 (R5); also elsewhere on the board
/A13: IC1.21 (A13), MP1.7 (R6); also elsewhere on the board
/A14: IC1.22 (A14), MP1.8 (R7); also elsewhere on the board
/A15: IC1.23 (A15), MP1.9 (R8); also elsewhere on the board
/D0: IC3.2 (A1); also elsewhere on the board
/D1: IC3.3 (A2); also elsewhere on the board
/D2: IC3.4 (A3); also elsewhere on the board
/D3: IC3.5 (A4); also elsewhere on the board
/D4: IC3.6 (A5); also elsewhere on the board
/D5: IC3.7 (A6); also elsewhere on the board
/D6: IC3.8 (A7); also elsewhere on the board
/D7: IC3.9 (A8); also elsewhere on the board
/ECLK: IC1.34 (E); also elsewhere on the board
/QCLK: IC1.35 (Q); also elsewhere on the board
/R~W: IC1.32 (R/~W), IC3.1 (DIR), MP1.10 (R9); also elsewhere on the board
/cpu/BUS_TXRX_ENABLE: IC1.6 (BA), IC3.19 (~OE)
/cpu/DN0: IC1.31 (D0), IC3.18 (B1)
/cpu/DN1: IC1.30 (D1), IC3.17 (B2)
/cpu/DN2: IC1.29 (D2), IC3.16 (B3)
/cpu/DN3: IC1.28 (D3), IC3.15 (B4)
/cpu/DN4: IC1.27 (D4), IC3.14 (B5)
/cpu/DN5: IC1.26 (D5), IC3.13 (B6)
/cpu/DN6: IC1.25 (D6), IC3.12 (B7)
/cpu/DN7: IC1.24 (D7), IC3.11 (B8)
/~FIRQ: IC1.4 (~FIRQ), R3.2; also elsewhere on the board
/~HALT: IC1.40 (~HALT), R5.2; also elsewhere on the board
/~IRQ: IC1.3 (~IRQ), R2.2; also elsewhere on the board
/~NMI: IC1.2 (~NMI), R4.2; also elsewhere on the board
/~RESET: C3.1, D12.2 (A), IC1.37 (~RESET), R1.2, SW2.1; also elsewhere on the board
GNDS: C1.1, C2.2, C3.2, C5.2, IC1.1 (VSS), IC1.39 (TSC), IC3.10 (GND), SW2.2; also elsewhere on the board

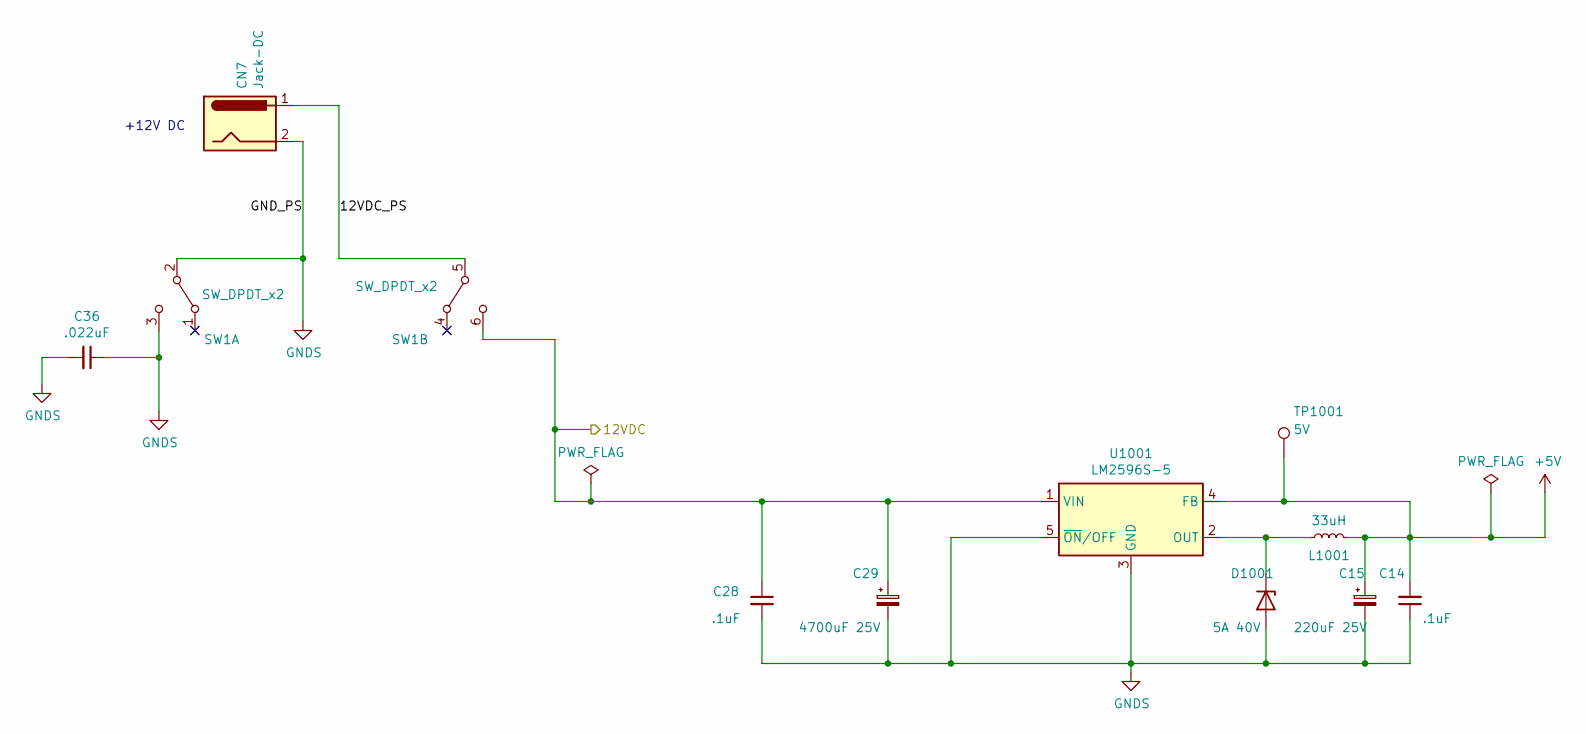
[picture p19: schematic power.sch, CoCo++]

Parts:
C14, C28: .1uF; C_0805_2012Metric_Pad1.18x1.45mm_HandSolder; Manufacturer part# CL21A106KAYNNNE
C15: 220uF 25V; CP_Elec_8x10; Manufacturer part# VEJ221M1ETR-0810
C29: 4700uF 25V; CP_Elec_18x22; Manufacturer part# VEJ472M1ETR-1821
C36: .022uF; C_0805_2012Metric_Pad1.18x1.45mm_HandSolder; Manufacturer part# CL21B223KBANNNC
CN7: Jack-DC; BarrelJack_CUI_PJ-063AH_Horizontal; Manufacturer part# PJ-063AH
D1001: 5A 40V; D_SMB; Manufacturer part# SS54B
L1001: 33uH; L_Sumida_CDMC6D28_7.25x6.5mm; Manufacturer part# MWSA0605S-330MT
SW1: SW_DPDT_x2; F2UEE; Manufacturer part# F2UEE
TP1001: 5V; TestPoint_Pad_3.0x3.0mm
U1001: LM2596S-5; TO-263-5_TabPin3; Manufacturer part# LM2596SX-5.0/NOPB

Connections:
+5V: C14.2, C15.1, L1001.2, TP1001.1, U1001.4 (FB); also elsewhere on the board
/power/12VDC: C28.1, C29.1, SW1.6 (C), U1001.1 (VIN); also elsewhere on the board
/power/12VDC_PS: CN7.1, SW1.5 (B)
GNDS: C14.1, C15.2, C28.2, C29.2, C36.1, C36.2, CN7.2, D1001.2 (A), SW1.2 (B), SW1.3 (C), U1001.3 (GND), U1001.5 (~ON~/OFF); also elsewhere on the board
unnamed: D1001.1 (K), L1001.1, U1001.2 (OUT)

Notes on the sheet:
+12V DC

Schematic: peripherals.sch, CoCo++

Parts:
BREAKOUT0: Conn_01x18_Male; PinHeader_1x18_P2.54mm_Vertical
C6, C7, C13, C47, C48, C1001: .1uF; C_0805_2012Metric_Pad1.18x1.45mm_HandSolder; Manufacturer part# CL21A106KAYNNNE
C16, C17, C20, C21, C25, C49: .022uF; C_0805_2012Metric_Pad1.18x1.45mm_HandSolder; Manufacturer part# CL21B223KBANNNC
C18, C19, C22, C23: 1800pF; C_0805_2012Metric_Pad1.18x1.45mm_HandSolder; Manufacturer part# 0805B182K500NT
C24: 10uF NP; C_Radial_D6.3mm_H5.0mm_P2.50mm; Manufacturer part# UVP1E100MDD1TD
C1002, C1003, C1004: .47uF; C_0805_2012Metric_Pad1.18x1.45mm_HandSolder; Manufacturer part# CL21B474KBFNNNE
CN2: Conn_01x16_Female; PinHeader_1x16_P2.54mm_Vertical; Manufacturer part# 6-520415-6
D5, D1002: 1N4148; D_SOD-323F; Manufacturer part# 1N4148WS
D8, D9, D10, D11: 1KF20-04; D_A-405_P10.16mm_Horizontal; Manufacturer part# D-GE-GEN PURP 75V
FB6, FB8, FB9, FB10: FB_28L0138-10R-10; Manufacturer part# 28L0138-10R-10
IC4, IC5: W65C21N6TPLG-14; PLCC-44_THT-Socket
IC7: SC77526; DIP-20_W7.62mm_Socket; Manufacturer part# 243-20-1-03
IC14: 74LS30; SOIC-14_3.9x8.7mm_P1.27mm; Manufacturer part# SN74LS30DR
IC15: 74LS04; SOIC-14_3.9x8.7mm_P1.27mm; Manufacturer part# SN74LS04DR
J1002: Conn_01x04_Male; PinHeader_1x04_P2.54mm_Vertical
JK1: Left Joystick; CUI_SDS-60J; Manufacturer part# SDS-60J
JK2: Right Joystick; CUI_SDS-60J; Manufacturer part# SDS-60J
JK3: RS232; CUI_SDS-40J; Manufacturer part# SDS-40J
JK4: Cassette; CUI_SDS-50J; Manufacturer part# SDS-50J
Q1001: MMBT9014C; SOT-23; LCSC LCSC
R6, R7, R21, R24, R59: 4.7K; R_1206_3216Metric_Pad1.30x1.75mm_HandSolder; Manufacturer part# 1206W4F4701T5E
R12, R1001, R1008: 10k; R_1206_3216Metric_Pad1.30x1.75mm_HandSolder; Manufacturer part# 1206W4F1002T5E
R13: 100 1W; R_2512_6332Metric_Pad1.40x3.35mm_HandSolder; Manufacturer part# 25121WF1000T4E
R14: 220 1W; R_2512_6332Metric_Pad1.40x3.35mm_HandSolder; Manufacturer part# 25121WJ0221T4E
R66: 7.5K; R_1206_3216Metric_Pad1.30x1.75mm_HandSolder; Manufacturer part# 1206W4F7501T5E
R1002, R1003: 100K; R_1206_3216Metric_Pad1.30x1.75mm_HandSolder; Manufacturer part# 1206W4F1003T5E
R1004, R1005, R1006: 5.1K; R_0805_2012Metric_Pad1.20x1.40mm_HandSolder; Manufacturer part# 0805W8F5101T5E
R1007: 20M; R_1206_3216Metric_Pad1.30x1.75mm_HandSolder; Manufacturer part# 1206W4J0206T5E
RY1: J0971CS5VDC.45; RELAY_J0971CS5VDC.45; Manufacturer part# J0971CS5VDC.45
U1002: MAX3232; SOIC-16_3.9x9.9mm_P1.27mm; Manufacturer part# MAX3232ESE+T
U1003: LM393; TSSOP-8_4.4x3mm_P0.65mm; Manufacturer part# LM393PT

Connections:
+5V: BREAKOUT0.18, C6.2, C7.2, C13.2, C47.2, C48.2, C1003.2, D5.1 (K), IC4.21 (VDD), IC5.21 (VDD), IC14.1, IC14.14 (VCC), R6.1, R7.1, R13.1, R21.2, R24.2, R59.1, R66.2, R1002.1, R1003.1, R1004.2, RY1.A1, U1002.16 (VCC), U1003.8 (V+); also elsewhere on the board
/A0: IC4.39 (RS0), IC5.39 (RS0); also elsewhere on the board
/A1: IC4.38 (RS1), IC5.38 (RS1); also elsewhere on the board
/A5: IC4.26 (CS1), IC15.3; also elsewhere on the board
/D0: IC4.36 (D0), IC5.36 (D0); also elsewhere on the board
/D1: IC4.35 (D1), IC5.35 (D1); also elsewhere on the board
/D2: IC4.34 (D2), IC5.34 (D2); also elsewhere on the board
/D3: IC4.33 (D3), IC5.33 (D3); also elsewhere on the board
/D4: IC4.32 (D4), IC5.32 (D4); also elsewhere on the board
/D5: IC4.31 (D5), IC5.31 (D5); also elsewhere on the board
/D6: IC4.30 (D6), IC5.30 (D6); also elsewhere on the board
/D7: IC4.29 (D7), IC5.29 (D7); also elsewhere on the board
/ECLK: IC4.28 (ENABLE), IC5.28 (ENABLE); also elsewhere on the board
/R~W: IC4.23 (R~W), IC5.23 (R~W); also elsewhere on the board
/gime/IL1: IC14.8; also elsewhere on the board
/gime/PIA_~CS2: IC4.25 (~CS2), IC5.25 (~CS2); also elsewhere on the board
/gime/SERINT: IC4.11 (PB0), U1002.9 (R2OUT); also elsewhere on the board
/gime/~HSYNC: IC5.44 (CA1); also elsewhere on the board
/gime/~VSYNC: IC5.19 (CB1); also elsewhere on the board
/peripherals/CASS_DATA_IN: C24.1, C25.2, JK4.4, R14.2, R1005.2
/peripherals/CASS_DATA_IN_TTL: IC4.3 (PA0), R1004.1, R1007.2, U1003.1; also elsewhere on the board
/peripherals/CASS_MTR_OUT: D5.2 (A), Q1001.3 (C), RY1.A2
/peripherals/CASS_M_ON_TTL: IC4.43 (CA2), Q1001.1 (B), R1001.2
/peripherals/CD_IN_RS232: JK3.1, U1002.13 (R1IN)
/peripherals/CD_IN_TTL: IC4.44 (CA1), U1002.12 (R1OUT)
/peripherals/Color Computer DAC/CASSETTE_OUT: FB6.1; also elsewhere on the board
/peripherals/Color Computer DAC/CASSETTE_SND_IN: C24.2; also elsewhere on the board
/peripherals/Color Computer DAC/D0: IC4.5 (PA2); also elsewhere on the board
/peripherals/Color Computer DAC/D1: IC4.6 (PA3); also elsewhere on the board
/peripherals/Color Computer DAC/D2: IC4.7 (PA4); also elsewhere on the board
/peripherals/Color Computer DAC/D3: IC4.8 (PA5); also elsewhere on the board
/peripherals/Color Computer DAC/D4: IC4.9 (PA6); also elsewhere on the board
/peripherals/Color Computer DAC/D5: IC4.10 (PA7); also elsewhere on the board
/peripherals/Color Computer DAC/SND_ENABLE: IC4.20 (CB2); also elsewhere on the board
/peripherals/HI: IC4.24 (CS0), IC5.24 (CS0), R6.2
/peripherals/IC4_PB4: IC4.15 (PB4), J1002.1
/peripherals/IC4_PB5: IC4.16 (PB5), J1002.2
/peripherals/IC4_PB6: IC4.17 (PB6), J1002.3
/peripherals/IC4_PB7: IC4.18 (PB7), J1002.4
/peripherals/JOY0: C16.1, JK2.1; also elsewhere on the board
/peripherals/JOY1: C17.2, JK2.2; also elsewhere on the board
/peripherals/JOY2: C20.1, JK1.1; also elsewhere on the board
/peripherals/JOY3: C21.2, JK1.2; also elsewhere on the board
/peripherals/K15: BREAKOUT0.15, CN2.15, IC4.13 (PB2), IC5.17 (PB6), R59.2
/peripherals/KR1: BREAKOUT0.1, CN2.1, D11.2 (A), IC5.3 (PA0), IC14.3
/peripherals/KR2: BREAKOUT0.2, CN2.2, D9.2 (A), IC5.4 (PA1), IC14.2
/peripherals/KR3: BREAKOUT0.4, CN2.4, D8.2 (A), IC5.5 (PA2), IC14.12
/peripherals/KR4: BREAKOUT0.5, CN2.5, D10.2 (A), IC5.6 (PA3), IC14.4
/peripherals/KR5: BREAKOUT0.6, CN2.6, IC5.7 (PA4), IC14.11
/peripherals/KR6: BREAKOUT0.7, CN2.7, IC5.8 (PA5), IC14.5
/peripherals/KR7: BREAKOUT0.8, CN2.8, IC5.9 (PA6), IC14.6
/peripherals/PA7: IC5.10 (PA7); also elsewhere on the board
/peripherals/RGB_OUT_10: IC4.14 (PB3); also elsewhere on the board
/peripherals/SELA: IC5.43 (CA2), R24.1; also elsewhere on the board
/peripherals/SELB: IC5.20 (CB2), R21.1; also elsewhere on the board
/peripherals/SERIAL_DATA_IN_RS232: JK3.2, R66.1, U1002.8 (R2IN)
/peripherals/SERIAL_OUT_RS232: JK3.4, U1002.7 (T2OUT)
/peripherals/SER_OUT_TTL: IC4.4 (PA1), U1002.10 (T2IN)
/peripherals/SOUND: R12.1; also elsewhere on the board
/~CART: IC4.19 (CB1), R7.2; also elsewhere on the board
/~FIRQ: IC4.41 (~IRQB), IC4.42 (~IRQA); also elsewhere on the board
/~IRQ: IC5.41 (~IRQB), IC5.42 (~IRQA); also elsewhere on the board
/~RESET: IC4.37 (~RESET), IC5.37 (~RESET); also elsewhere on the board
GNDS: BREAKOUT0.3, BREAKOUT0.17, C6.1, C7.1, C13.1, C16.2, C17.1, C18.2, C19.2, C20.2, C21.1, C22.2, C23.2, C25.1, C47.1, C48.1, C49.1, C1004.2, CN2.3, D1002.2 (A), FB8.2, FB9.1, FB10.1, IC4.1 (VSS), IC5.1 (VSS), IC14.7 (GND), JK4.2, Q1001.2 (E), R14.1, R1001.1, R1008.2, U1002.15 (GND), U1003.4 (V-); also elsewhere on the board
unnamed: BREAKOUT0.9, CN2.9, IC5.11 (PB0)
unnamed: BREAKOUT0.10, CN2.10, IC5.12 (PB1)
unnamed: BREAKOUT0.11, CN2.11, IC5.13 (PB2)
unnamed: BREAKOUT0.12, CN2.12, IC5.14 (PB3)
unnamed: BREAKOUT0.13, CN2.13, IC5.15 (PB4)
unnamed: BREAKOUT0.14, CN2.14, IC5.16 (PB5)
unnamed: BREAKOUT0.16, CN2.16, IC5.18 (PB7)
unnamed: C18.1, D11.1 (K), JK2.4
unnamed: C19.1, D8.1 (K), JK2.6
unnamed: C22.1, D9.1 (K), JK1.4
unnamed: C23.1, D10.1 (K), JK1.6
unnamed: C49.2, JK1.5, JK2.5, R13.2
unnamed: C1001.1, U1002.3 (C1-)
unnamed: C1001.2, U1002.1 (C1+)
unnamed: C1002.1, U1002.5 (C2-)
unnamed: C1002.2, U1002.4 (C2+)
unnamed: C1003.1, U1002.2 (VS+)
unnamed: C1004.1, U1002.6 (VS-)
unnamed: D1002.1 (K), R1005.1, R1006.2
unnamed: FB6.2, JK4.5
unnamed: FB8.1, JK3.3
unnamed: FB9.2, JK2.3
unnamed: FB10.2, JK1.3
unnamed: IC4.12 (PB1), R12.2
unnamed: IC5.26 (CS1), IC15.4
unnamed: JK4.1, RY1.14
unnamed: JK4.3, RY1.11
unnamed 218: R1002.2, R1006.1, U1003.3 (+); also elsewhere on the board
unnamed 219: R1003.2, R1007.1, R1008.1, U1003.2 (-); also elsewhere on the board

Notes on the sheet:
RY1 is not the original relay the original is no longer made.
R24 is not in the original schematic and it is listed as not used in the parts list. I added it allows the the W65C21N6TPG-14 to work as well.
There are two connectors here. The keyboard connector and a breakout header.

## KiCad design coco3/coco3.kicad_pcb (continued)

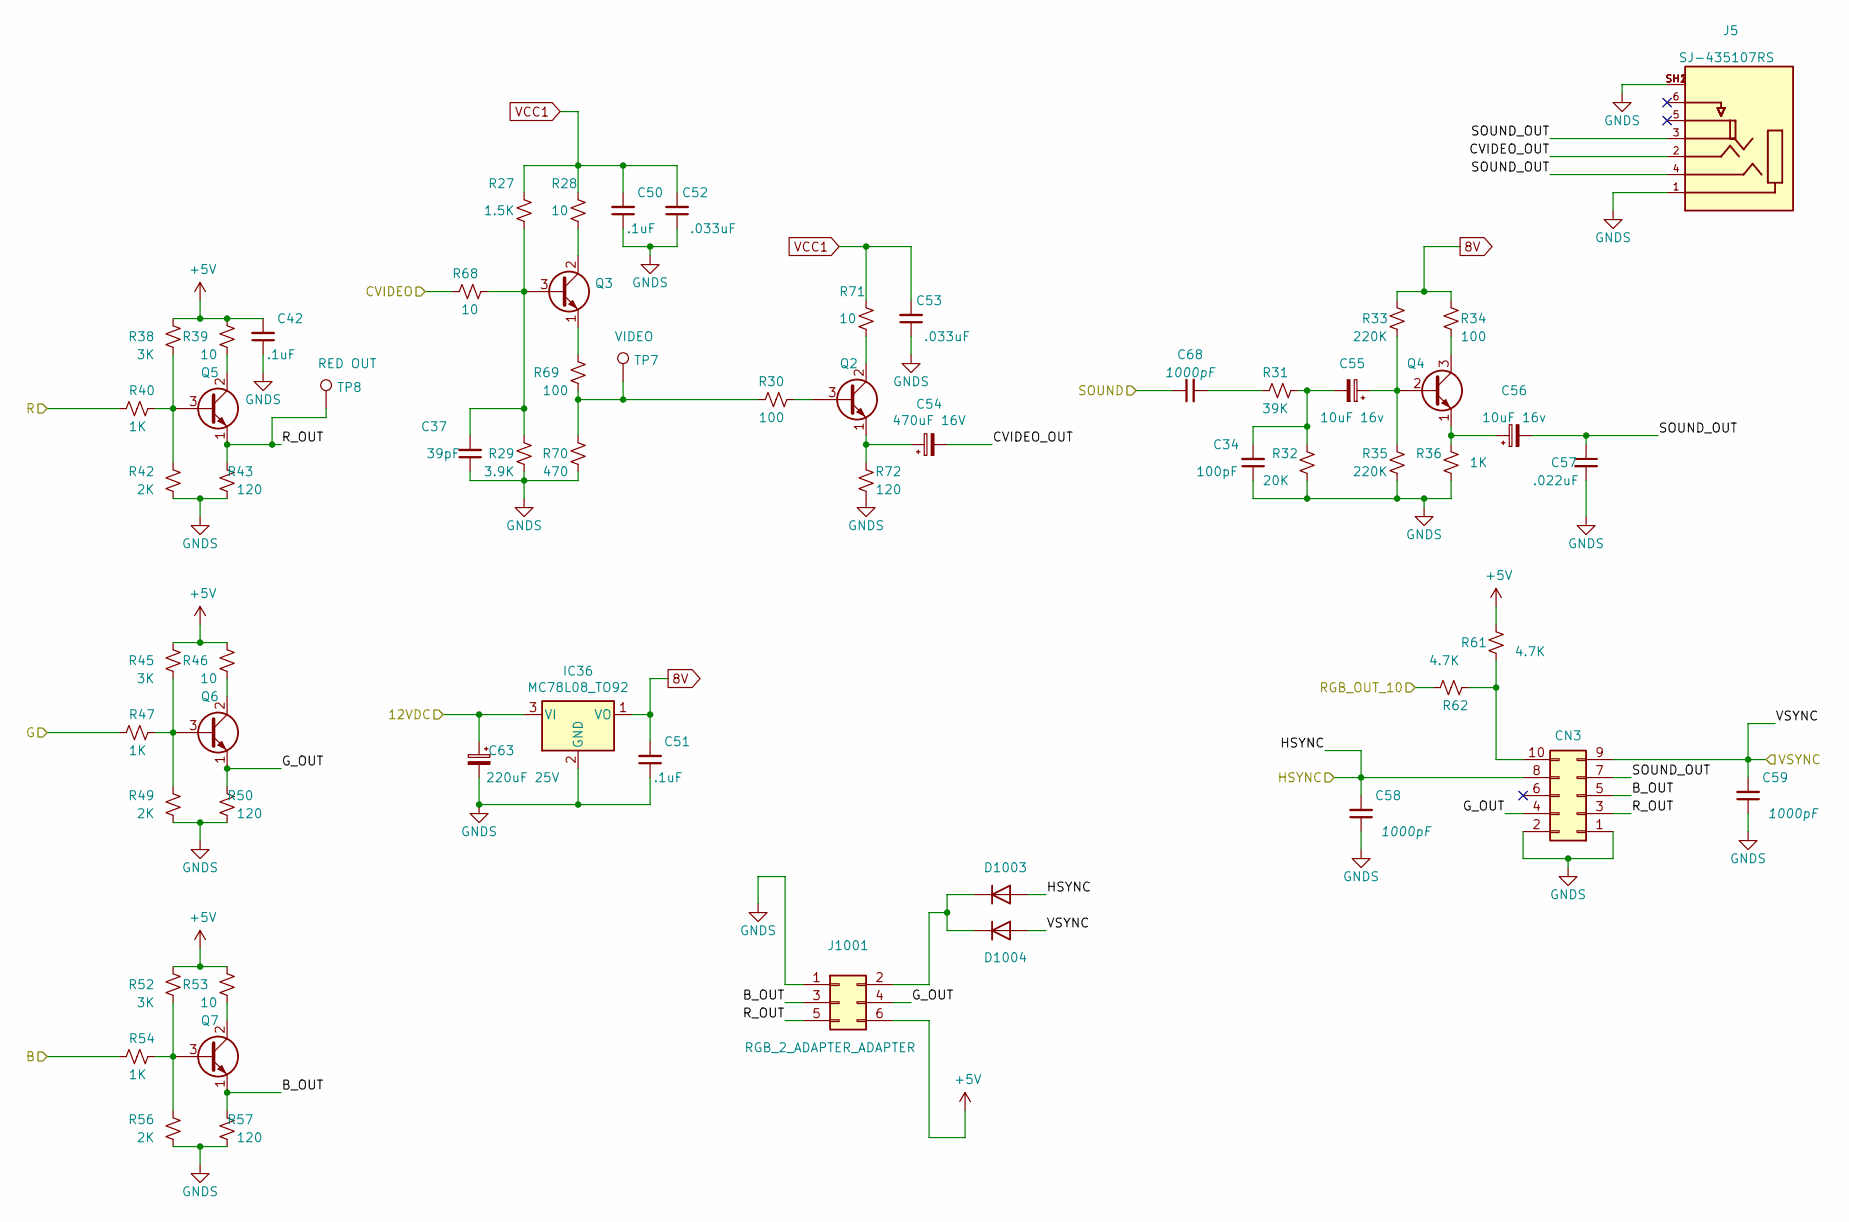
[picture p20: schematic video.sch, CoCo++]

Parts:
C34: 100pF; C_0805_2012Metric_Pad1.18x1.45mm_HandSolder; Manufacturer part# CL21C101JBANNNC
C37: 39pF; C_0805_2012Metric_Pad1.18x1.45mm_HandSolder; Manufacturer part# 0805N390J500CT
C42, C50, C51: .1uF; C_0805_2012Metric_Pad1.18x1.45mm_HandSolder; Manufacturer part# CL21A106KAYNNNE
C52, C53: .033uF; C_0805_2012Metric_Pad1.18x1.45mm_HandSolder; Manufacturer part# 0805B333K500NT
C54: 470uF 16V; CP_Elec_8x10; Manufacturer part# VEJ471M1CTR-0810
C55, C56: 10uF 16v; CP_EIA-3216-18_Kemet-A; Manufacturer part# TAJA106K016RNJ
C57: .022uF; C_0805_2012Metric_Pad1.18x1.45mm_HandSolder; Manufacturer part# CL21B223KBANNNC
C58, C59, C68: 1000pF; C_0805_2012Metric_Pad1.18x1.45mm_HandSolder; Manufacturer part# CL21B102KBCNNNC
C63: 220uF 25V; CP_Elec_8x10; Manufacturer part# VEJ221M1ETR-0810
CN3: Conn_02x05_Odd_Even; PinHeader_2x05_P2.54mm_Vertical; Manufacturer part# PRPC005DAAN-RC
D1003, D1004: 1N4148; D_SOD-323F; Manufacturer part# 1N4148WS
IC36: MC78L08_TO92; TO-92_Inline; Manufacturer part# UA78L08ACLPRE3
J5: SJ-435107RS; CUI_SJ-435107RS
J1001: RGB_2_ADAPTER_ADAPTER; PinHeader_2x03_P2.54mm_Horizontal; Manufacturer part# 75867-131LF
Q2, Q3, Q5, Q6, Q7: 2SC945(NTE85); TO-92L_Inline; Manufacturer part# NTE85
Q4: MPSA13(NTE46); TO-92L_Inline; Manufacturer part# NTE46
R27: 1.5K; R_1206_3216Metric_Pad1.30x1.75mm_HandSolder; Manufacturer part# UNI-ROYAL(Uniroyal Elec)
R28, R39, R46, R53, R68, R71: 10; R_1206_3216Metric_Pad1.30x1.75mm_HandSolder; Manufacturer part# 1206W4F100JT5E
R29: 3.9K; R_1206_3216Metric_Pad1.30x1.75mm_HandSolder; Manufacturer part# 1206W4F3901T5E
R30, R34, R69: 100; R_1206_3216Metric_Pad1.30x1.75mm_HandSolder; Manufacturer part# 1206W4F1000T5E
R31: 39K; R_1206_3216Metric_Pad1.30x1.75mm_HandSolder; Manufacturer part# 1206W4F3902T5E
R32: 20K; R_1206_3216Metric_Pad1.30x1.75mm_HandSolder; Manufacturer part# 1206W4F620KT5E
R33, R35: 220K; R_1206_3216Metric_Pad1.30x1.75mm_HandSolder; Manufacturer part# 1206W4F2203T5E
R36, R40, R47, R54: 1K; R_1206_3216Metric_Pad1.30x1.75mm_HandSolder; Manufacturer part# 1206W4F1001T5
R38, R45, R52: 3K; R_1206_3216Metric_Pad1.30x1.75mm_HandSolder; Manufacturer part# 1206W4F3001T5E
R42, R49, R56: 2K; R_1206_3216Metric_Pad1.30x1.75mm_HandSolder; Manufacturer part# 1206W4F2001T5E
R43, R50, R57, R72: 120; R_1206_3216Metric_Pad1.30x1.75mm_HandSolder; Manufacturer part# 1206W4F1200T5E
R61, R62: 4.7K; R_1206_3216Metric_Pad1.30x1.75mm_HandSolder; Manufacturer part# 1206W4F4701T5E
R70: 470; R_1206_3216Metric_Pad1.30x1.75mm_HandSolder; Manufacturer part# 1206W4J0471T5E
TP7: VIDEO; TestPoint_Pad_3.0x3.0mm
TP8: RED OUT; TestPoint_Pad_3.0x3.0mm

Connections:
8V: C51.2, IC36.1 (VO), R33.1, R34.2
+5V: C42.2, J1001.6, R38.2, R39.2, R45.2, R46.2, R52.2, R53.2, R61.1; also elsewhere on the board
/gime/B: R54.2; also elsewhere on the board
/gime/CVIDEO: R68.1; also elsewhere on the board
/gime/G: R47.2; also elsewhere on the board
/gime/HSYNC: C58.2, CN3.8, D1003.2 (A); also elsewhere on the board
/gime/R: R40.2; also elsewhere on the board
/gime/VSYNC: C59.2, CN3.9, D1004.2 (A); also elsewhere on the board
/peripherals/RGB_OUT_10: R62.1; also elsewhere on the board
/peripherals/SOUND: C68.1; also elsewhere on the board
/power/12VDC: C63.1, IC36.3 (VI); also elsewhere on the board
/video/B_OUT: CN3.5, J1001.3, Q7.1 (E), R57.2
/video/CVIDEO_OUT: C54.2, J5.2
/video/G_OUT: CN3.4, J1001.4, Q6.1 (E), R50.2
/video/R_OUT: CN3.3, J1001.5, Q5.1 (E), R43.2, TP8.1
/video/SOUND_OUT: C56.2, C57.1, CN3.7, J5.3, J5.4
GNDS: C34.1, C37.1, C42.1, C50.1, C51.1, C52.1, C53.1, C57.2, C58.1, C59.1, C63.2, CN3.1, CN3.2, IC36.2 (GND), J5.1, J5.SH1, J5.SH2, J1001.1, R29.1, R32.2, R35.2, R36.2, R42.1, R43.1, R49.1, R50.1, R56.1, R57.1, R70.1, R72.1; also elsewhere on the board
unnamed: C34.2, C55.2, R31.2, R32.1
unnamed: C37.2, Q3.3 (B), R27.1, R29.2, R68.2
unnamed: C54.1, Q2.1 (E), R72.2
unnamed: C55.1, Q4.2 (B), R33.2, R35.1
unnamed: C56.1, Q4.1 (E), R36.1
unnamed: C68.2, R31.1
unnamed: CN3.10, R61.2, R62.2
unnamed: D1003.1 (K), D1004.1 (K), J1001.2
unnamed: Q2.2 (C), R71.1
unnamed: Q2.3 (B), R30.2
unnamed: Q3.1 (E), R69.2
unnamed: Q3.2 (C), R28.1
unnamed: Q4.3 (C), R34.1
unnamed: Q5.2 (C), R39.1
unnamed: Q5.3 (B), R38.1, R40.1, R42.2
unnamed: Q6.2 (C), R46.1
unnamed: Q6.3 (B), R45.1, R47.1, R49.2
unnamed: Q7.2 (C), R53.1
unnamed: Q7.3 (B), R52.1, R54.1, R56.2
unnamed: R30.1, R69.1, R70.2, TP7.1
VCC1: C50.2, C52.2, C53.2, R27.2, R28.2, R71.2; also elsewhere on the board

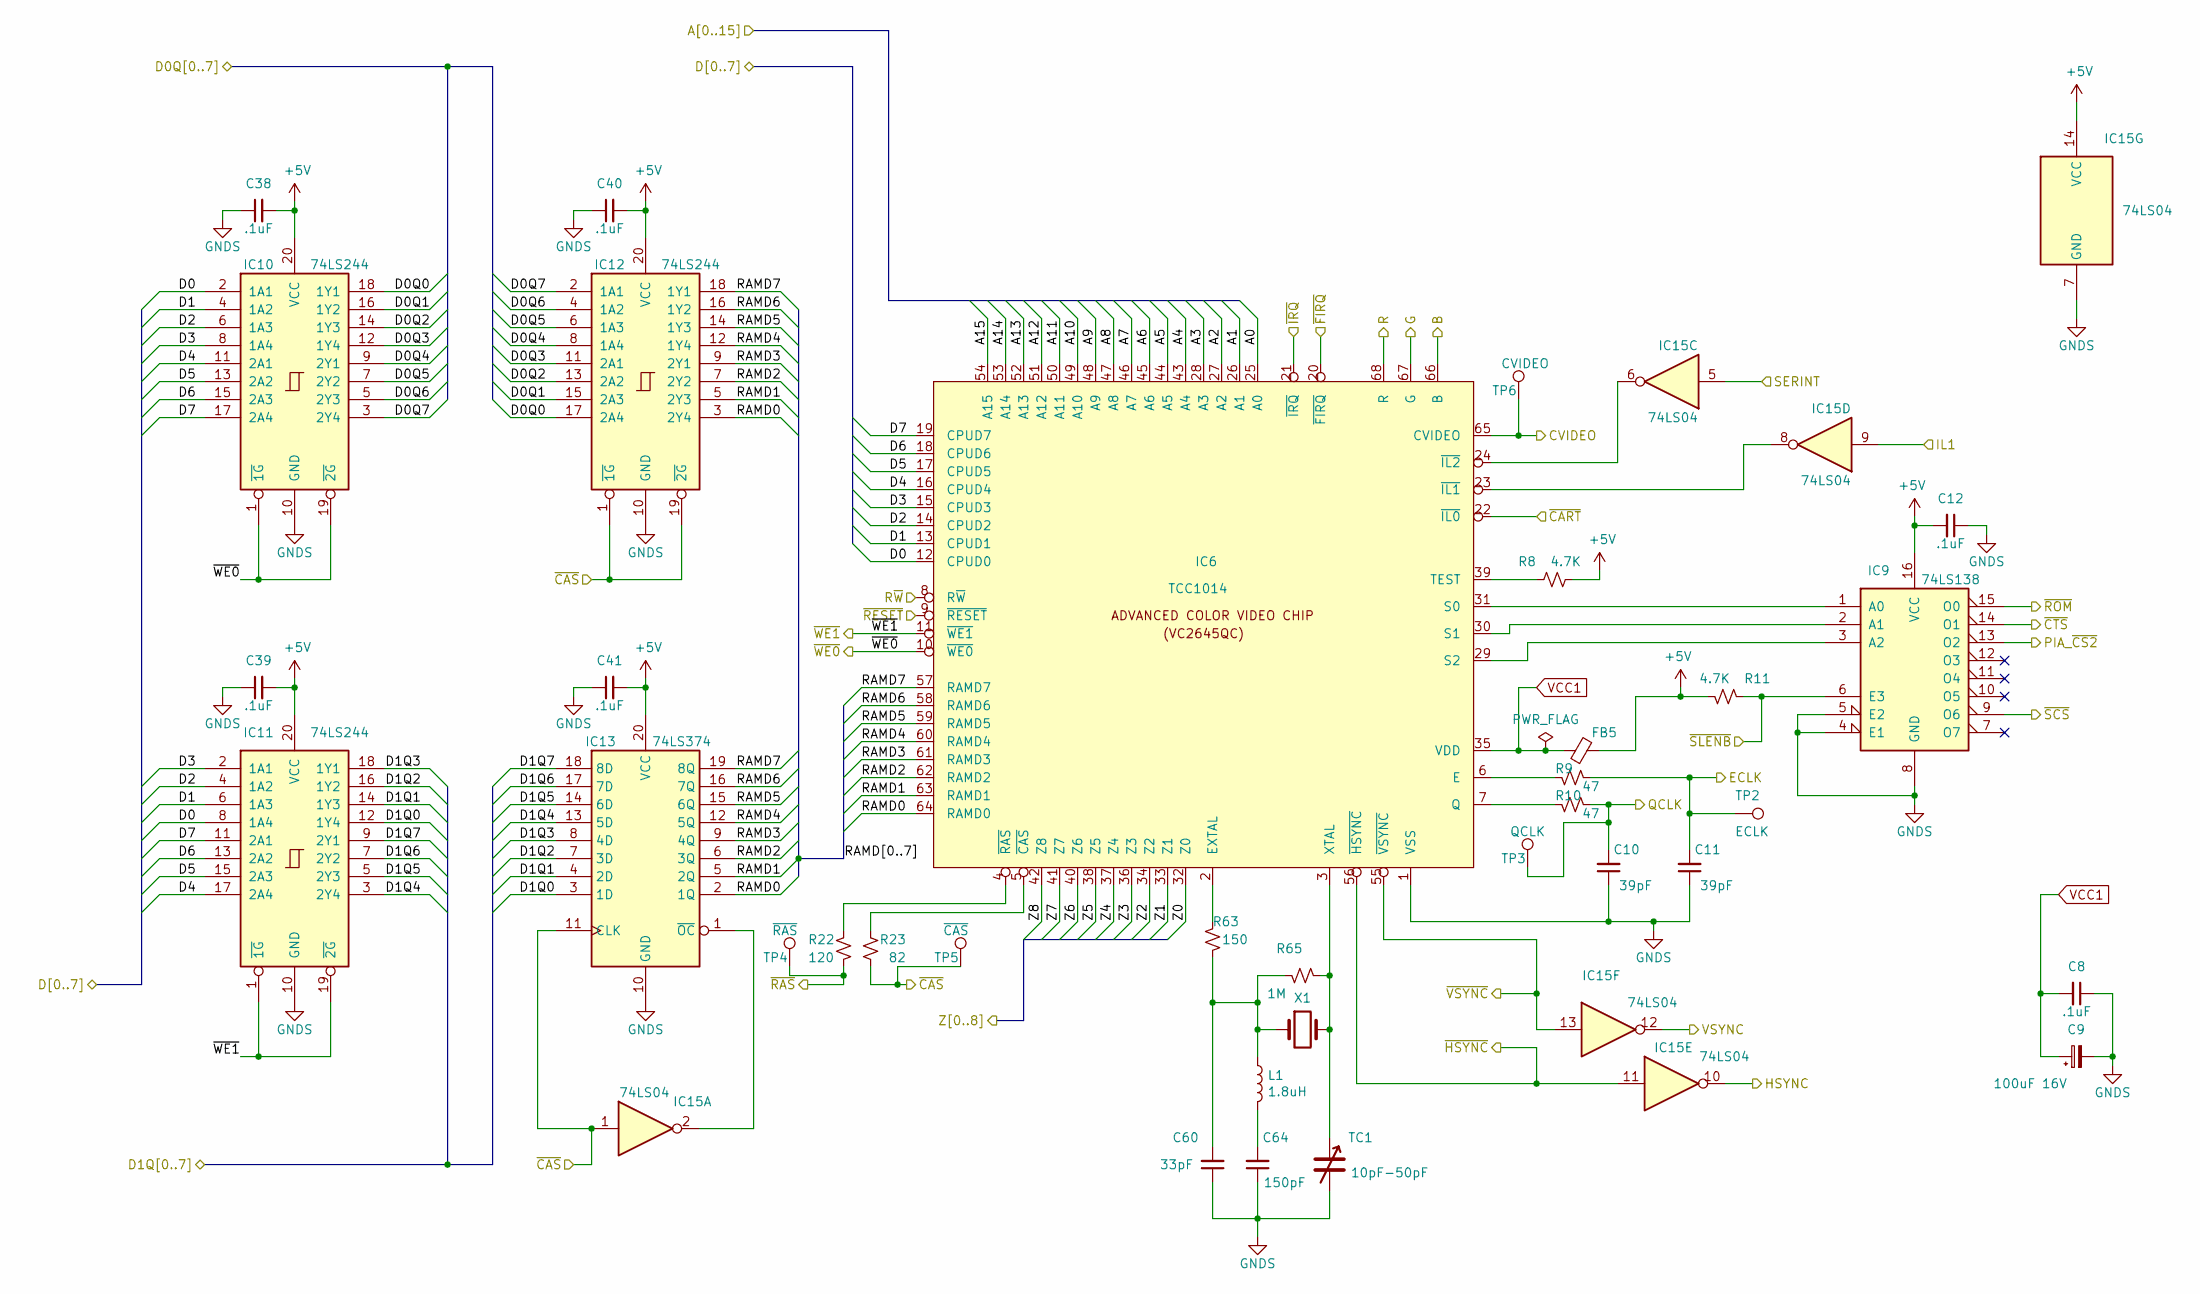
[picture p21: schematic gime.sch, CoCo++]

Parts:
C8, C12, C38, C39, C40, C41: .1uF; C_0805_2012Metric_Pad1.18x1.45mm_HandSolder; Manufacturer part# CL21A106KAYNNNE
C9: 100uF 16V; CP_Elec_6.3x5.3; Manufacturer part# VEJ101M1CTR-0605
C10, C11: 39pF; C_0805_2012Metric_Pad1.18x1.45mm_HandSolder; Manufacturer part# 0805N390J500CT
C60: 33pF; C_0805_2012Metric_Pad1.18x1.45mm_HandSolder; Manufacturer part# CL21C330JBANNNC
C64: 150pF; C_0805_2012Metric_Pad1.18x1.45mm_HandSolder; Manufacturer part# 0805B151K500NT
FB5: FB_28L0138-10R-10; Manufacturer part# 28L0138-10R-10
IC6: TCC1014; PLCC-68_THT-Socket; Manufacturer part# A-CCS 068-G-T
IC9: 74LS138; SOP-16_3.9x9.9mm_P1.27mm; Manufacturer part# XL74LS138
IC10, IC11, IC12: 74LS244; SOIC-20W_7.5x12.8mm_P1.27mm; Manufacturer part# SN74LS244DWR
IC13: 74LS374; SOIC-20W_7.5x12.8mm_P1.27mm; Manufacturer part# SN74LS374NSR
IC15: 74LS04; SOIC-14_3.9x8.7mm_P1.27mm; Manufacturer part# SN74LS04DR
L1: 1.8uH; L_Axial_L9.5mm_D4.0mm_P12.70mm_Horizontal_Fastron_SMCC; Manufacturer part# 1537-18K
R8, R11: 4.7K; R_1206_3216Metric_Pad1.30x1.75mm_HandSolder; Manufacturer part# 1206W4F4701T5E
R9, R10: 47; R_1206_3216Metric_Pad1.30x1.75mm_HandSolder; Manufacturer part# 1206W4J0470T5E
R22: 120; R_1206_3216Metric_Pad1.30x1.75mm_HandSolder; Manufacturer part# 1206W4F1200T5E
R23: 82; R_1206_3216Metric_Pad1.30x1.75mm_HandSolder; Manufacturer part# 1206W4F820JT5E
R63: 150; R_1206_3216Metric_Pad1.30x1.75mm_HandSolder; Manufacturer part# 1206W4F1500T5E
R65: 1M; R_1206_3216Metric_Pad1.30x1.75mm_HandSolder; Manufacturer part# 1206W4F1004T5E
TC1: 10pF-50pF; C_Rect_L7.2mm_W7.2mm_P5.00mm_FKS2_FKP2_MKS2_MKP2; Manufacturer part# GKG60015
TP2: ECLK; TestPoint_Pad_3.0x3.0mm
TP3: QCLK; TestPoint_Pad_3.0x3.0mm
TP4: ~RAS; TestPoint_Pad_3.0x3.0mm
TP5: ~CAS; TestPoint_Pad_3.0x3.0mm
TP6: CVIDEO; TestPoint_Pad_3.0x3.0mm
X1: 28.63636 MHz; XTAL_ECS-286.3-20-46X; Manufacturer part# ECS-286.3-20-46X

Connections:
+5V: C12.2, C38.2, C39.2, C40.2, C41.2, FB5.2, IC9.16 (VCC), IC10.20 (VCC), IC11.20 (VCC), IC12.20 (VCC), IC13.20 (VCC), IC15.14 (VCC), R8.2, R11.2; also elsewhere on the board
/A0: IC6.25 (A0); also elsewhere on the board
/A1: IC6.26 (A1); also elsewhere on the board
/A2: IC6.27 (A2); also elsewhere on the board
/A3: IC6.28 (A3); also elsewhere on the board
/A4: IC6.43 (A4); also elsewhere on the board
/A5: IC6.44 (A5); also elsewhere on the board
/A6: IC6.45 (A6); also elsewhere on the board
/A7: IC6.46 (A7); also elsewhere on the board
/A8: IC6.47 (A8); also elsewhere on the board
/A9: IC6.48 (A9); also elsewhere on the board
/A10: IC6.49 (A10); also elsewhere on the board
/A11: IC6.50 (A11); also elsewhere on the board
/A12: IC6.51 (A12); also elsewhere on the board
/A13: IC6.52 (A13); also elsewhere on the board
/A14: IC6.53 (A14); also elsewhere on the board
/A15: IC6.54 (A15); also elsewhere on the board
/D0: IC6.12 (CPUD0), IC10.2 (1A1), IC11.8 (1A4); also elsewhere on the board
/D1: IC6.13 (CPUD1), IC10.4 (1A2), IC11.6 (1A3); also elsewhere on the board
/D2: IC6.14 (CPUD2), IC10.6 (1A3), IC11.4 (1A2); also elsewhere on the board
/D3: IC6.15 (CPUD3), IC10.8 (1A4), IC11.2 (1A1); also elsewhere on the board
/D4: IC6.16 (CPUD4), IC10.11 (2A1), IC11.17 (2A4); also elsewhere on the board
/D5: IC6.17 (CPUD5), IC10.13 (2A2), IC11.15 (2A3); also elsewhere on the board
/D6: IC6.18 (CPUD6), IC10.15 (2A3), IC11.13 (2A2); also elsewhere on the board
/D7: IC6.19 (CPUD7), IC10.17 (2A4), IC11.11 (2A1); also elsewhere on the board
/ECLK: C11.2, R9.1, TP2.1; also elsewhere on the board
/QCLK: C10.2, R10.1, TP3.1; also elsewhere on the board
/R~W: IC6.8 (R~W); also elsewhere on the board
/dram/D0Q0: IC10.18 (1Y1), IC12.17 (2A4); also elsewhere on the board
/dram/D0Q1: IC10.16 (1Y2), IC12.15 (2A3); also elsewhere on the board
/dram/D0Q2: IC10.14 (1Y3), IC12.13 (2A2); also elsewhere on the board
/dram/D0Q3: IC10.12 (1Y4), IC12.11 (2A1); also elsewhere on the board
/dram/D0Q4: IC10.9 (2Y1), IC12.8 (1A4); also elsewhere on the board
/dram/D0Q5: IC10.7 (2Y2), IC12.6 (1A3); also elsewhere on the board
/dram/D0Q6: IC10.5 (2Y3), IC12.4 (1A2); also elsewhere on the board
/dram/D0Q7: IC10.3 (2Y4), IC12.2 (1A1); also elsewhere on the board
/dram/D1Q0: IC11.12 (1Y4), IC13.3 (1D); also elsewhere on the board
/dram/D1Q1: IC11.14 (1Y3), IC13.4 (2D); also elsewhere on the board
/dram/D1Q2: IC11.16 (1Y2), IC13.7 (3D); also elsewhere on the board
/dram/D1Q3: IC11.18 (1Y1), IC13.8 (4D); also elsewhere on the board
/dram/D1Q4: IC11.3 (2Y4), IC13.13 (5D); also elsewhere on the board
/dram/D1Q5: IC11.5 (2Y3), IC13.14 (6D); also elsewhere on the board
/dram/D1Q6: IC11.7 (2Y2), IC13.17 (7D); also elsewhere on the board
/dram/D1Q7: IC11.9 (2Y1), IC13.18 (8D); also elsewhere on the board
/dram/Z0: IC6.32 (Z0); also elsewhere on the board
/dram/Z1: IC6.33 (Z1); also elsewhere on the board
/dram/Z2: IC6.34 (Z2); also elsewhere on the board
/dram/Z3: IC6.36 (Z3); also elsewhere on the board
/dram/Z4: IC6.37 (Z4); also elsewhere on the board
/dram/Z5: IC6.38 (Z5); also elsewhere on the board
/dram/Z6: IC6.40 (Z6); also elsewhere on the board
/dram/Z7: IC6.41 (Z7); also elsewhere on the board
/dram/Z8: IC6.42 (Z8); also elsewhere on the board
/dram/~CAS: IC12.1 (~1G), IC12.19 (~2G), IC13.11 (CLK), IC15.1, R23.1, TP5.1; also elsewhere on the board
/dram/~RAS: R22.1, TP4.1; also elsewhere on the board
/dram/~WE0: IC6.10 (~WE0), IC10.1 (~1G), IC10.19 (~2G); also elsewhere on the board
/dram/~WE1: IC6.11 (~WE1), IC11.1 (~1G), IC11.19 (~2G); also elsewhere on the board
/gime/B: IC6.66 (B); also elsewhere on the board
/gime/CVIDEO: IC6.65 (CVIDEO), TP6.1; also elsewhere on the board
/gime/G: IC6.67 (G); also elsewhere on the board
/gime/HSYNC: IC15.10; also elsewhere on the board
/gime/IL1: IC15.9; also elsewhere on the board
/gime/PIA_~CS2: IC9.13 (O2); also elsewhere on the board
/gime/R: IC6.68 (R); also elsewhere on the board
/gime/RAMD0: IC6.64 (RAMD0), IC12.3 (2Y4), IC13.2 (1Q)
/gime/RAMD1: IC6.63 (RAMD1), IC12.5 (2Y3), IC13.5 (2Q)
/gime/RAMD2: IC6.62 (RAMD2), IC12.7 (2Y2), IC13.6 (3Q)
/gime/RAMD3: IC6.61 (RAMD3), IC12.9 (2Y1), IC13.9 (4Q)
/gime/RAMD4: IC6.60 (RAMD4), IC12.12 (1Y4), IC13.12 (5Q)
/gime/RAMD5: IC6.59 (RAMD5), IC12.14 (1Y3), IC13.15 (6Q)
/gime/RAMD6: IC6.58 (RAMD6), IC12.16 (1Y2), IC13.16 (7Q)
/gime/RAMD7: IC6.57 (RAMD7), IC12.18 (1Y1), IC13.19 (8Q)
/gime/SERINT: IC15.5; also elsewhere on the board
/gime/VSYNC: IC15.12; also elsewhere on the board
/gime/~HSYNC: IC6.56 (~HSYNC), IC15.11; also elsewhere on the board
/gime/~ROM: IC9.15 (O0); also elsewhere on the board
/gime/~VSYNC: IC6.55 (~VSYNC), IC15.13; also elsewhere on the board
/~CART: IC6.22 (~IL0); also elsewhere on the board
/~CTS: IC9.14 (O1); also elsewhere on the board
/~FIRQ: IC6.20 (~FIRQ); also elsewhere on the board
/~IRQ: IC6.21 (~IRQ); also elsewhere on the board
/~RESET: IC6.9 (~RESET); also elsewhere on the board
/~SCS: IC9.9 (O6); also elsewhere on the board
/~SLENB: IC9.6 (E3), R11.1; also elsewhere on the board
GNDS: C8.1, C9.2, C10.1, C11.1, C12.1, C38.1, C39.1, C40.1, C41.1, C60.1, C64.1, IC6.1 (VSS), IC9.4 (E1), IC9.5 (E2), IC9.8 (GND), IC10.10 (GND), IC11.10 (GND), IC12.10 (GND), IC13.10 (GND), IC15.7 (GND), TC1.2; also elsewhere on the board
unnamed: C60.2, L1.1, R63.2, R65.2, X1.1
unnamed: C64.2, L1.2
unnamed: IC6.2 (EXTAL), R63.1
unnamed: IC6.3 (XTAL), R65.1, TC1.1, X1.2
unnamed: IC6.4 (~RAS), R22.2
unnamed: IC6.5 (~CAS), R23.2
unnamed: IC6.6 (E), R9.2
unnamed: IC6.7 (Q), R10.2
unnamed: IC6.29 (S2), IC9.3 (A2)
unnamed: IC6.30 (S1), IC9.2 (A1)
unnamed: IC6.31 (S0), IC9.1 (A0)
unnamed: IC6.39 (TEST), R8.1
unnamed: IC13.1 (~OC), IC15.2
unnamed: IC6.24 (~IL2), IC15.6
unnamed: IC6.23 (~IL1), IC15.8
VCC1: C8.2, C9.1, FB5.1, IC6.35 (VDD); also elsewhere on the board

Board: 2 copper layers, 211 parts (1 on the bottom side), 222 nets, no tracks yet.

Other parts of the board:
C30: 20pF; C_0805_2012Metric_Pad1.18x1.45mm_HandSolder
R15: 100K; R_0603_1608Metric_Pad0.98x0.95mm_HandSolder
R16: 330K; R_0805_2012Metric_Pad1.20x1.40mm_HandSolder
R17: 160K; R_0603_1608Metric_Pad0.98x0.95mm_HandSolder
R18, R19: 82K; R_0805_2012Metric_Pad1.20x1.40mm_HandSolder
R20: 40.2K; R_0603_1608Metric_Pad0.98x0.95mm_HandSolder
R25: 300K; R_0805_2012Metric_Pad1.20x1.40mm_HandSolder
R26: 20K; R_0805_2012Metric_Pad1.20x1.40mm_HandSolder
R37, R41: 10K; R_0805_2012Metric_Pad1.20x1.40mm_HandSolder
R44: 10M; R_0805_2012Metric_Pad1.20x1.40mm_HandSolder
R48: 1K; R_0805_2012Metric_Pad1.20x1.40mm_HandSolder
U1: 74LS367; SOIC-16_3.9x9.9mm_P1.27mm
U2: TS5A3166DBVR; SOT-23-5
U3: LM393; TSSOP-8_4.4x3mm_P0.65mm
U4: CD4052B; HTSSOP-16-1EP_4.4x5mm_P0.65mm_EP3x3mm

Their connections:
+5V: R15.2, R48.2, U1.16, U2.5, U3.8, U4.16; also elsewhere on the board
/SND_IN_2: U4.15; also elsewhere on the board
/peripherals/CASS_DATA_IN_TTL: U3.7; also elsewhere on the board
/peripherals/Color Computer DAC/CASSETTE_OUT: C30.1, R15.1, R16.1, R17.1, R18.2, R19.1, R20.1, R26.1, R37.1, U3.2; also elsewhere on the board
/peripherals/Color Computer DAC/CASSETTE_SND_IN: U4.14; also elsewhere on the board
/peripherals/Color Computer DAC/D0: U1.2; also elsewhere on the board
/peripherals/Color Computer DAC/D1: U1.4; also elsewhere on the board
/peripherals/Color Computer DAC/D2: U1.6; also elsewhere on the board
/peripherals/Color Computer DAC/D3: U1.10; also elsewhere on the board
/peripherals/Color Computer DAC/D4: U1.12; also elsewhere on the board
/peripherals/Color Computer DAC/D5: U1.14; also elsewhere on the board
/peripherals/Color Computer DAC/DAC_OUT: R18.1, R25.2, U4.12
/peripherals/Color Computer DAC/SND_ENABLE: U2.4; also elsewhere on the board
/peripherals/JOY0: U4.1; also elsewhere on the board
/peripherals/JOY1: U4.5; also elsewhere on the board
/peripherals/JOY2: U4.2; also elsewhere on the board
/peripherals/JOY3: U4.4; also elsewhere on the board
/peripherals/PA7: R44.1, R48.1, U3.1; also elsewhere on the board
/peripherals/SELA: U4.10; also elsewhere on the board
/peripherals/SELB: U4.9; also elsewhere on the board
/peripherals/SOUND: U2.2; also elsewhere on the board
GNDS: C30.2, R25.1, U1.1, U1.8, U1.15, U2.3, U3.4, U4.6, U4.7, U4.8, U4.11; also elsewhere on the board
unnamed: R16.2, U1.3
unnamed: R17.2, U1.5
unnamed: R19.2, U1.7
unnamed: R20.2, U1.9
unnamed: R26.2, U1.11
unnamed: R37.2, U1.13
unnamed: R41.1, R44.2, U3.3
unnamed: R41.2, U4.3
unnamed 218: U3.5; also elsewhere on the board
unnamed 219: U3.6; also elsewhere on the board
unnamed: U2.1, U4.13

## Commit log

2021-08-31 changed title to CoCo++ and changed revision to 1.0.0
    [coco3.kicad_pcb, coco3.sch, cpu.sch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]
2021-09-02 -replaced PIA's with he PLCC44 package versions -removed RF modulator -removed DRAM
    [coco3.kicad_pcb, dram.sch, gime.sch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]
2021-09-03 -repplaced a whole bunch of THT components with SMT components
    [coco3.kicad_pcb, coco3.sch, cpu.sch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]
2021-09-04 -converted more components from THT to SMD -replaced SALT chip with replacement circuitry
    [CUI_DEVICES_SJ-435107RS.step, coco3.kicad_pcb, coco3.sch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]
2021-09-12 routed the board
    [SRP6540.stp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]
2021-12-10 added replacement circuitry for SC77526P DAC/ADC chip
    [coco3.kicad_pcb, coco3.sch, color_computer_dac.sch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]
2021-12-10 cleaned up some components
    [peripherals.sch]

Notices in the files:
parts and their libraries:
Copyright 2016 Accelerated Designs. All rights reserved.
